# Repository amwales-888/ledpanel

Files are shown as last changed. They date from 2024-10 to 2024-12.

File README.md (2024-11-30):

# ledpanel
32x32 LED panel

Using 16 8x8 1.9mm LED modules to make a larger 32x32 8cm panel.
Adding shift registers and a small py32 microcontroller to multiplex the display.
The panel is broken out into two boards, the first a simple breakout and the
second is a plugin board that holds the mcu and shift registers. The panel
design does not overhang any edges so multiple panels can be connected together.

<table>
  <tr>
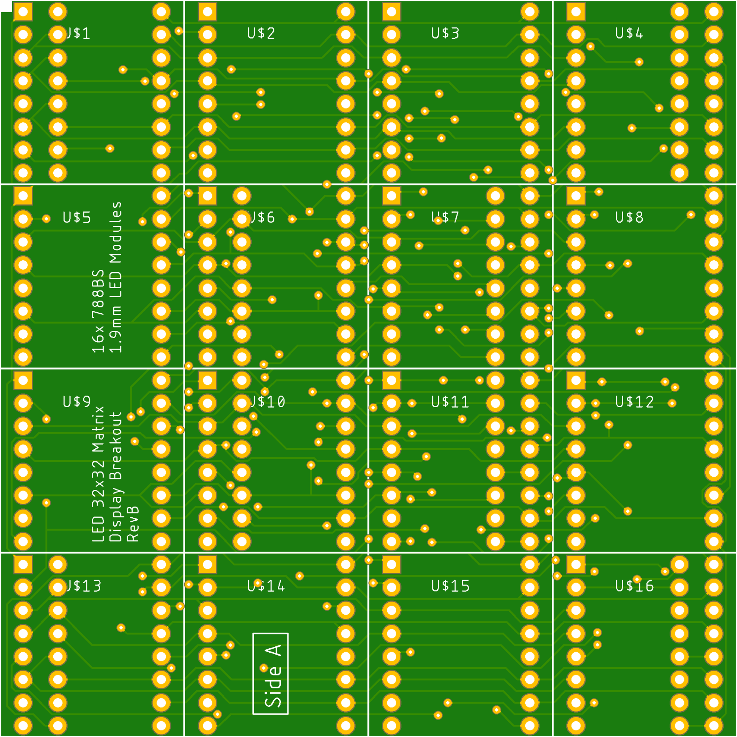
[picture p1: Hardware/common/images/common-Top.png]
    <td> </td>
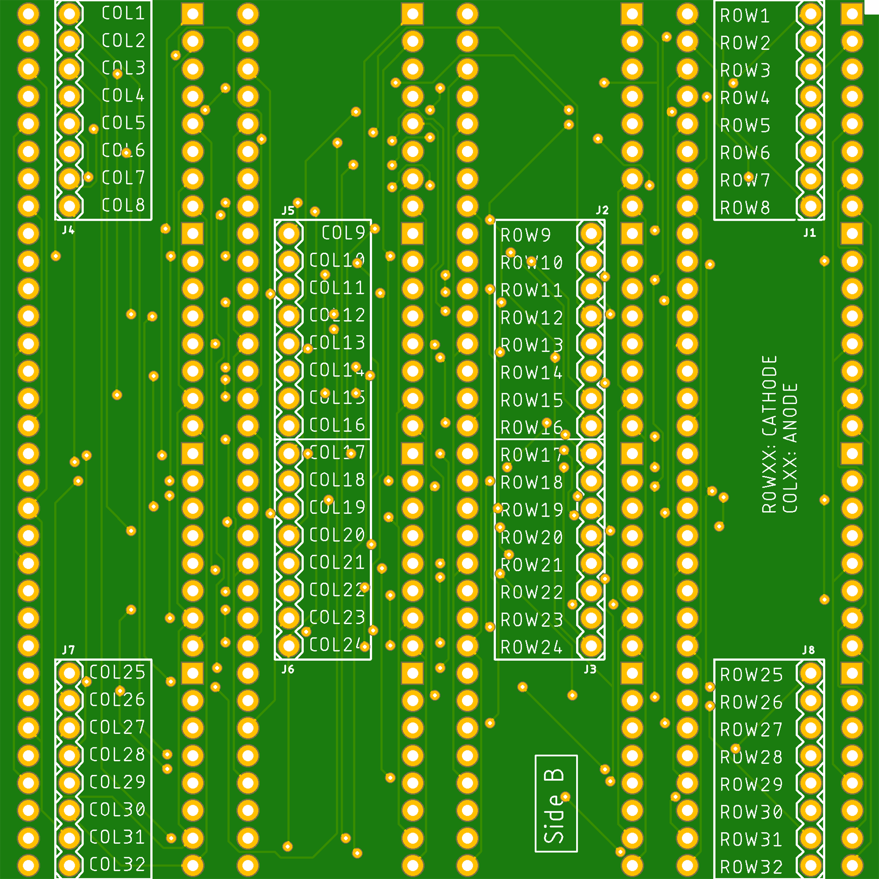
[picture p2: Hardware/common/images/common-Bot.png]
    <td> </td>
  </tr>
  <tr>
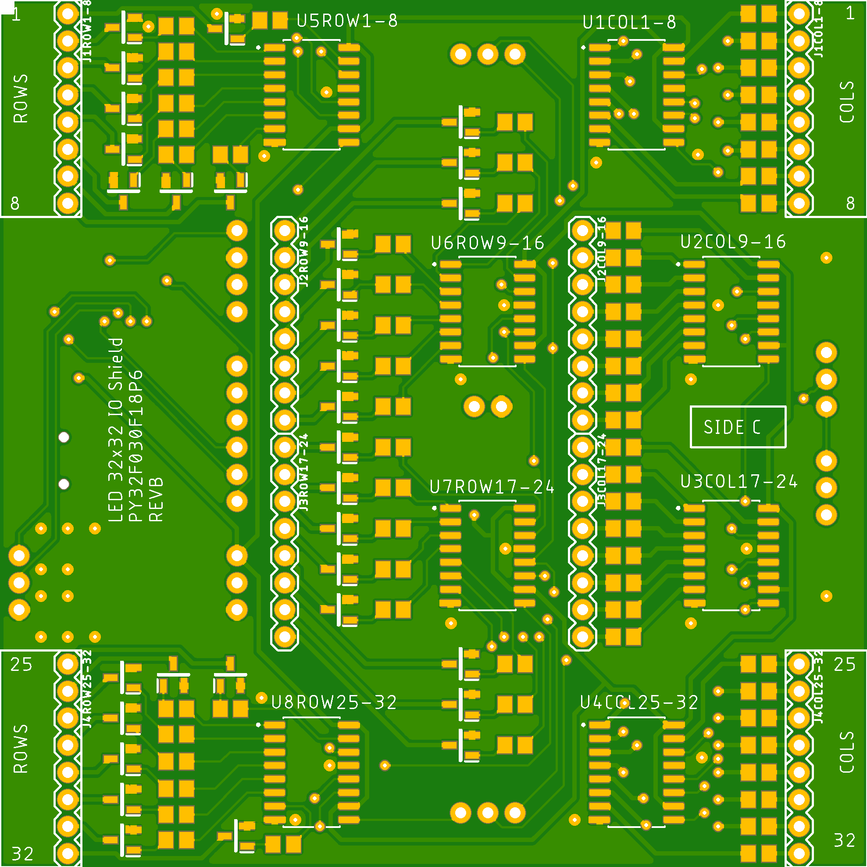
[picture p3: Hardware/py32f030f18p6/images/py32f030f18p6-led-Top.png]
    <td> </td>
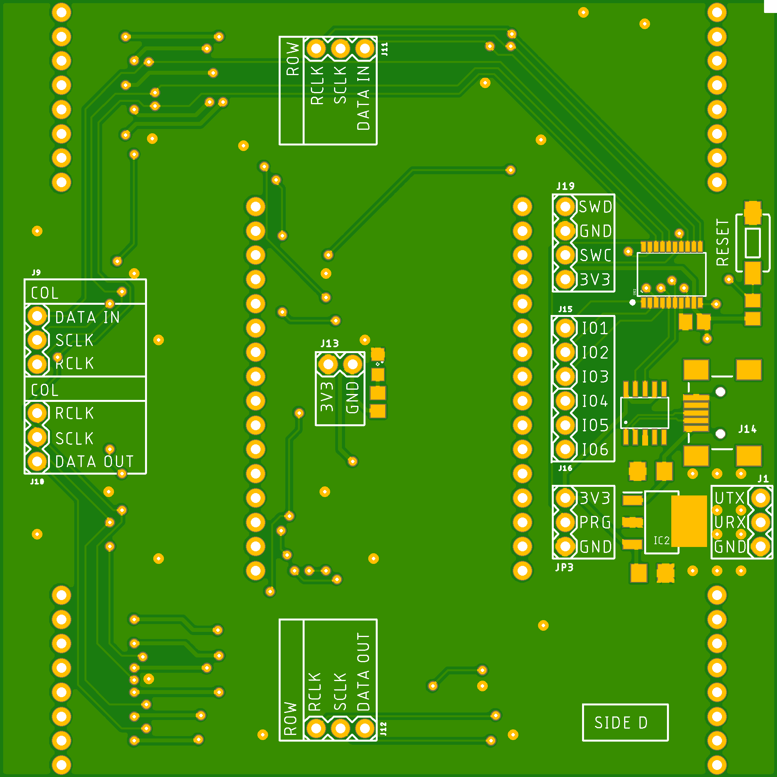
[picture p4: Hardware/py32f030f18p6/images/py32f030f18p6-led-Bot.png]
    <td> </td>
  </tr>
</table>

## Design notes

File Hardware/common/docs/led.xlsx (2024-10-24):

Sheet: Sheet1
 | 0 | 1 | 2 | 3 | 4
0 | 0 | 0 | 1 | 0 | 0 | 0 | 66 | 127 | 64 | 0
1 | 0 | 1 | 1 | 0 | 0
2 | 0 | 0 | 1 | 0 | 0
3 | 0 | 0 | 1 | 0 | 0
4 | 0 | 0 | 1 | 0 | 0
5 | 0 | 0 | 1 | 0 | 0
6 | 0 | 1 | 1 | 1 | 0
7 | 0 | 0 | 0 | 0 | 0
0 | 0 | 1 | 1 | 1 | 0 | 66 | 97 | 81 | 73 | 70
1 | 1 | 0 | 0 | 0 | 1
2 | 0 | 0 | 0 | 0 | 1
3 | 0 | 0 | 0 | 1 | 0
4 | 0 | 0 | 1 | 0 | 0
5 | 0 | 1 | 0 | 0 | 0
6 | 1 | 1 | 1 | 1 | 1
7 | 0 | 0 | 0 | 0 | 0
0 | 1 | 1 | 1 | 1 | 0 | 65 | 73 | 73 | 73 | 54
1 | 0 | 0 | 0 | 0 | 1
2 | 0 | 0 | 0 | 0 | 1
3 | 0 | 1 | 1 | 1 | 0
4 | 0 | 0 | 0 | 0 | 1
5 | 0 | 0 | 0 | 0 | 1
6 | 1 | 1 | 1 | 1 | 0
7 | 0 | 0 | 0 | 0 | 0
0 | 1 | 0 | 0 | 0 | 1 | 15 | 8 | 8 | 8 | 127
1 | 1 | 0 | 0 | 0 | 1
2 | 1 | 0 | 0 | 0 | 1
3 | 1 | 1 | 1 | 1 | 1
4 | 0 | 0 | 0 | 0 | 1
5 | 0 | 0 | 0 | 0 | 1
6 | 0 | 0 | 0 | 0 | 1
7 | 0 | 0 | 0 | 0 | 0
0 | 1 | 1 | 1 | 1 | 1 | 79 | 73 | 73 | 73 | 49
1 | 1 | 0 | 0 | 0 | 0
2 | 1 | 0 | 0 | 0 | 0
3 | 1 | 1 | 1 | 1 | 0
4 | 0 | 0 | 0 | 0 | 1
5 | 0 | 0 | 0 | 0 | 1
6 | 1 | 1 | 1 | 1 | 0
7 | 0 | 0 | 0 | 0 | 0
0 | 0 | 1 | 1 | 1 | 0 | 62 | 73 | 73 | 73 | 48
1 | 1 | 0 | 0 | 0 | 0
2 | 1 | 0 | 0 | 0 | 0
3 | 1 | 1 | 1 | 1 | 0
4 | 1 | 0 | 0 | 0 | 1
5 | 1 | 0 | 0 | 0 | 1
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

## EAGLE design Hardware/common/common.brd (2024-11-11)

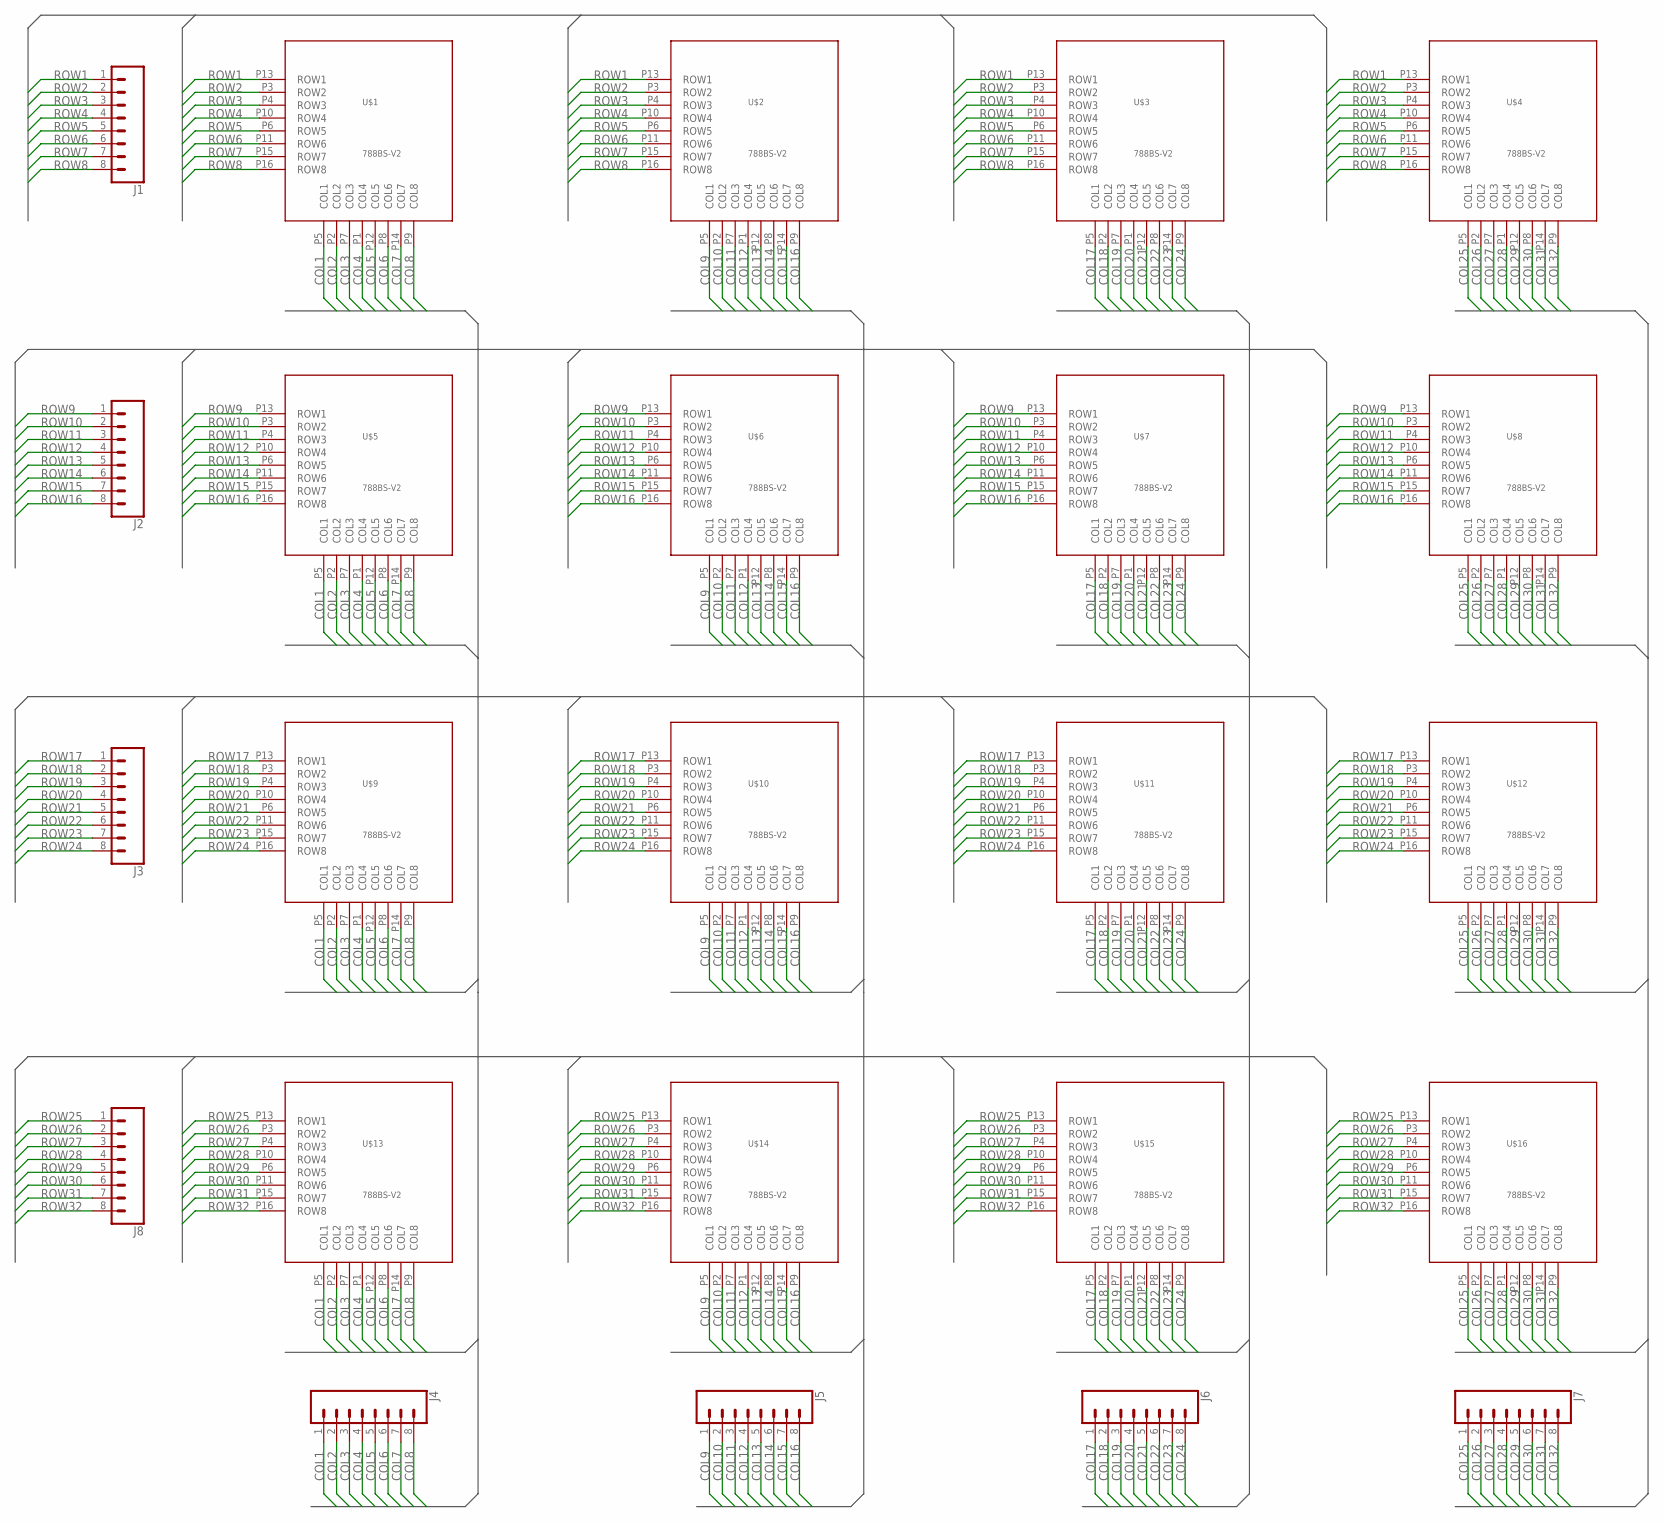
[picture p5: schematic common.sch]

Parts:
J1, J2, J3, J4, J5, J6, J7, J8: CONN_08"; 1X08
U$1, U$2, U$3, U$4, U$5, U$6, U$7, U$8, U$9, U$10, U$11, U$12, U$13, U$14, U$15, U$16: 788BS-V2; 788BS8X81.9MM-V2

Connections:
COL1: J4.1, U$1.P5 (COL1), U$5.P5 (COL1), U$9.P5 (COL1), U$13.P5 (COL1)
COL2: J4.2, U$1.P2 (COL2), U$5.P2 (COL2), U$9.P2 (COL2), U$13.P2 (COL2)
COL3: J4.3, U$1.P7 (COL3), U$5.P7 (COL3), U$9.P7 (COL3), U$13.P7 (COL3)
COL4: J4.4, U$1.P1 (COL4), U$5.P1 (COL4), U$9.P1 (COL4), U$13.P1 (COL4)
COL5: J4.5, U$1.P12 (COL5), U$5.P12 (COL5), U$9.P12 (COL5), U$13.P12 (COL5)
COL6: J4.6, U$1.P8 (COL6), U$5.P8 (COL6), U$9.P8 (COL6), U$13.P8 (COL6)
COL7: J4.7, U$1.P14 (COL7), U$5.P14 (COL7), U$9.P14 (COL7), U$13.P14 (COL7)
COL8: J4.8, U$1.P9 (COL8), U$5.P9 (COL8), U$9.P9 (COL8), U$13.P9 (COL8)
COL9: J5.1, U$2.P5 (COL1), U$6.P5 (COL1), U$10.P5 (COL1), U$14.P5 (COL1)
COL10: J5.2, U$2.P2 (COL2), U$6.P2 (COL2), U$10.P2 (COL2), U$14.P2 (COL2)
COL11: J5.3, U$2.P7 (COL3), U$6.P7 (COL3), U$10.P7 (COL3), U$14.P7 (COL3)
COL12: J5.4, U$2.P1 (COL4), U$6.P1 (COL4), U$10.P1 (COL4), U$14.P1 (COL4)
COL13: J5.5, U$2.P12 (COL5), U$6.P12 (COL5), U$10.P12 (COL5), U$14.P12 (COL5)
COL14: J5.6, U$2.P8 (COL6), U$6.P8 (COL6), U$10.P8 (COL6), U$14.P8 (COL6)
COL15: J5.7, U$2.P14 (COL7), U$6.P14 (COL7), U$10.P14 (COL7), U$14.P14 (COL7)
COL16: J5.8, U$2.P9 (COL8), U$6.P9 (COL8), U$10.P9 (COL8), U$14.P9 (COL8)
COL17: J6.1, U$3.P5 (COL1), U$7.P5 (COL1), U$11.P5 (COL1), U$15.P5 (COL1)
COL18: J6.2, U$3.P2 (COL2), U$7.P2 (COL2), U$11.P2 (COL2), U$15.P2 (COL2)
COL19: J6.3, U$3.P7 (COL3), U$7.P7 (COL3), U$11.P7 (COL3), U$15.P7 (COL3)
COL20: J6.4, U$3.P1 (COL4), U$7.P1 (COL4), U$11.P1 (COL4), U$15.P1 (COL4)
COL21: J6.5, U$3.P12 (COL5), U$7.P12 (COL5), U$11.P12 (COL5), U$15.P12 (COL5)
COL22: J6.6, U$3.P8 (COL6), U$7.P8 (COL6), U$11.P8 (COL6), U$15.P8 (COL6)
COL23: J6.7, U$3.P14 (COL7), U$7.P14 (COL7), U$11.P14 (COL7), U$15.P14 (COL7)
COL24: J6.8, U$3.P9 (COL8), U$7.P9 (COL8), U$11.P9 (COL8), U$15.P9 (COL8)
COL25: J7.1, U$4.P5 (COL1), U$8.P5 (COL1), U$12.P5 (COL1), U$16.P5 (COL1)
COL26: J7.2, U$4.P2 (COL2), U$8.P2 (COL2), U$12.P2 (COL2), U$16.P2 (COL2)
COL27: J7.3, U$4.P7 (COL3), U$8.P7 (COL3), U$12.P7 (COL3), U$16.P7 (COL3)
COL28: J7.4, U$4.P1 (COL4), U$8.P1 (COL4), U$12.P1 (COL4), U$16.P1 (COL4)
COL29: J7.5, U$4.P12 (COL5), U$8.P12 (COL5), U$12.P12 (COL5), U$16.P12 (COL5)
COL30: J7.6, U$4.P8 (COL6), U$8.P8 (COL6), U$12.P8 (COL6), U$16.P8 (COL6)
COL31: J7.7, U$4.P14 (COL7), U$8.P14 (COL7), U$12.P14 (COL7), U$16.P14 (COL7)
COL32: J7.8, U$4.P9 (COL8), U$8.P9 (COL8), U$12.P9 (COL8), U$16.P9 (COL8)
ROW1: J1.1, U$1.P13 (ROW1), U$2.P13 (ROW1), U$3.P13 (ROW1), U$4.P13 (ROW1)
ROW2: J1.2, U$1.P3 (ROW2), U$2.P3 (ROW2), U$3.P3 (ROW2), U$4.P3 (ROW2)
ROW3: J1.3, U$1.P4 (ROW3), U$2.P4 (ROW3), U$3.P4 (ROW3), U$4.P4 (ROW3)
ROW4: J1.4, U$1.P10 (ROW4), U$2.P10 (ROW4), U$3.P10 (ROW4), U$4.P10 (ROW4)
ROW5: J1.5, U$1.P6 (ROW5), U$2.P6 (ROW5), U$3.P6 (ROW5), U$4.P6 (ROW5)
ROW6: J1.6, U$1.P11 (ROW6), U$2.P11 (ROW6), U$3.P11 (ROW6), U$4.P11 (ROW6)
ROW7: J1.7, U$1.P15 (ROW7), U$2.P15 (ROW7), U$3.P15 (ROW7), U$4.P15 (ROW7)
ROW8: J1.8, U$1.P16 (ROW8), U$2.P16 (ROW8), U$3.P16 (ROW8), U$4.P16 (ROW8)
ROW9: J2.1, U$5.P13 (ROW1), U$6.P13 (ROW1), U$7.P13 (ROW1), U$8.P13 (ROW1)
ROW10: J2.2, U$5.P3 (ROW2), U$6.P3 (ROW2), U$7.P3 (ROW2), U$8.P3 (ROW2)
ROW11: J2.3, U$5.P4 (ROW3), U$6.P4 (ROW3), U$7.P4 (ROW3), U$8.P4 (ROW3)
ROW12: J2.4, U$5.P10 (ROW4), U$6.P10 (ROW4), U$7.P10 (ROW4), U$8.P10 (ROW4)
ROW13: J2.5, U$5.P6 (ROW5), U$6.P6 (ROW5), U$7.P6 (ROW5), U$8.P6 (ROW5)
ROW14: J2.6, U$5.P11 (ROW6), U$6.P11 (ROW6), U$7.P11 (ROW6), U$8.P11 (ROW6)
ROW15: J2.7, U$5.P15 (ROW7), U$6.P15 (ROW7), U$7.P15 (ROW7), U$8.P15 (ROW7)
ROW16: J2.8, U$5.P16 (ROW8), U$6.P16 (ROW8), U$7.P16 (ROW8), U$8.P16 (ROW8)
ROW17: J3.1, U$9.P13 (ROW1), U$10.P13 (ROW1), U$11.P13 (ROW1), U$12.P13 (ROW1)
ROW18: J3.2, U$9.P3 (ROW2), U$10.P3 (ROW2), U$11.P3 (ROW2), U$12.P3 (ROW2)
ROW19: J3.3, U$9.P4 (ROW3), U$10.P4 (ROW3), U$11.P4 (ROW3), U$12.P4 (ROW3)
ROW20: J3.4, U$9.P10 (ROW4), U$10.P10 (ROW4), U$11.P10 (ROW4), U$12.P10 (ROW4)
ROW21: J3.5, U$9.P6 (ROW5), U$10.P6 (ROW5), U$11.P6 (ROW5), U$12.P6 (ROW5)
ROW22: J3.6, U$9.P11 (ROW6), U$10.P11 (ROW6), U$11.P11 (ROW6), U$12.P11 (ROW6)
ROW23: J3.7, U$9.P15 (ROW7), U$10.P15 (ROW7), U$11.P15 (ROW7), U$12.P15 (ROW7)
ROW24: J3.8, U$9.P16 (ROW8), U$10.P16 (ROW8), U$11.P16 (ROW8), U$12.P16 (ROW8)
ROW25: J8.1, U$13.P13 (ROW1), U$14.P13 (ROW1), U$15.P13 (ROW1), U$16.P13 (ROW1)
ROW26: J8.2, U$13.P3 (ROW2), U$14.P3 (ROW2), U$15.P3 (ROW2), U$16.P3 (ROW2)
ROW27: J8.3, U$13.P4 (ROW3), U$14.P4 (ROW3), U$15.P4 (ROW3), U$16.P4 (ROW3)
ROW28: J8.4, U$13.P10 (ROW4), U$14.P10 (ROW4), U$15.P10 (ROW4), U$16.P10 (ROW4)
ROW29: J8.5, U$13.P6 (ROW5), U$14.P6 (ROW5), U$15.P6 (ROW5), U$16.P6 (ROW5)
ROW30: J8.6, U$13.P11 (ROW6), U$14.P11 (ROW6), U$15.P11 (ROW6), U$16.P11 (ROW6)
ROW31: J8.7, U$13.P15 (ROW7), U$14.P15 (ROW7), U$15.P15 (ROW7), U$16.P15 (ROW7)
ROW32: J8.8, U$13.P16 (ROW8), U$14.P16 (ROW8), U$15.P16 (ROW8), U$16.P16 (ROW8)

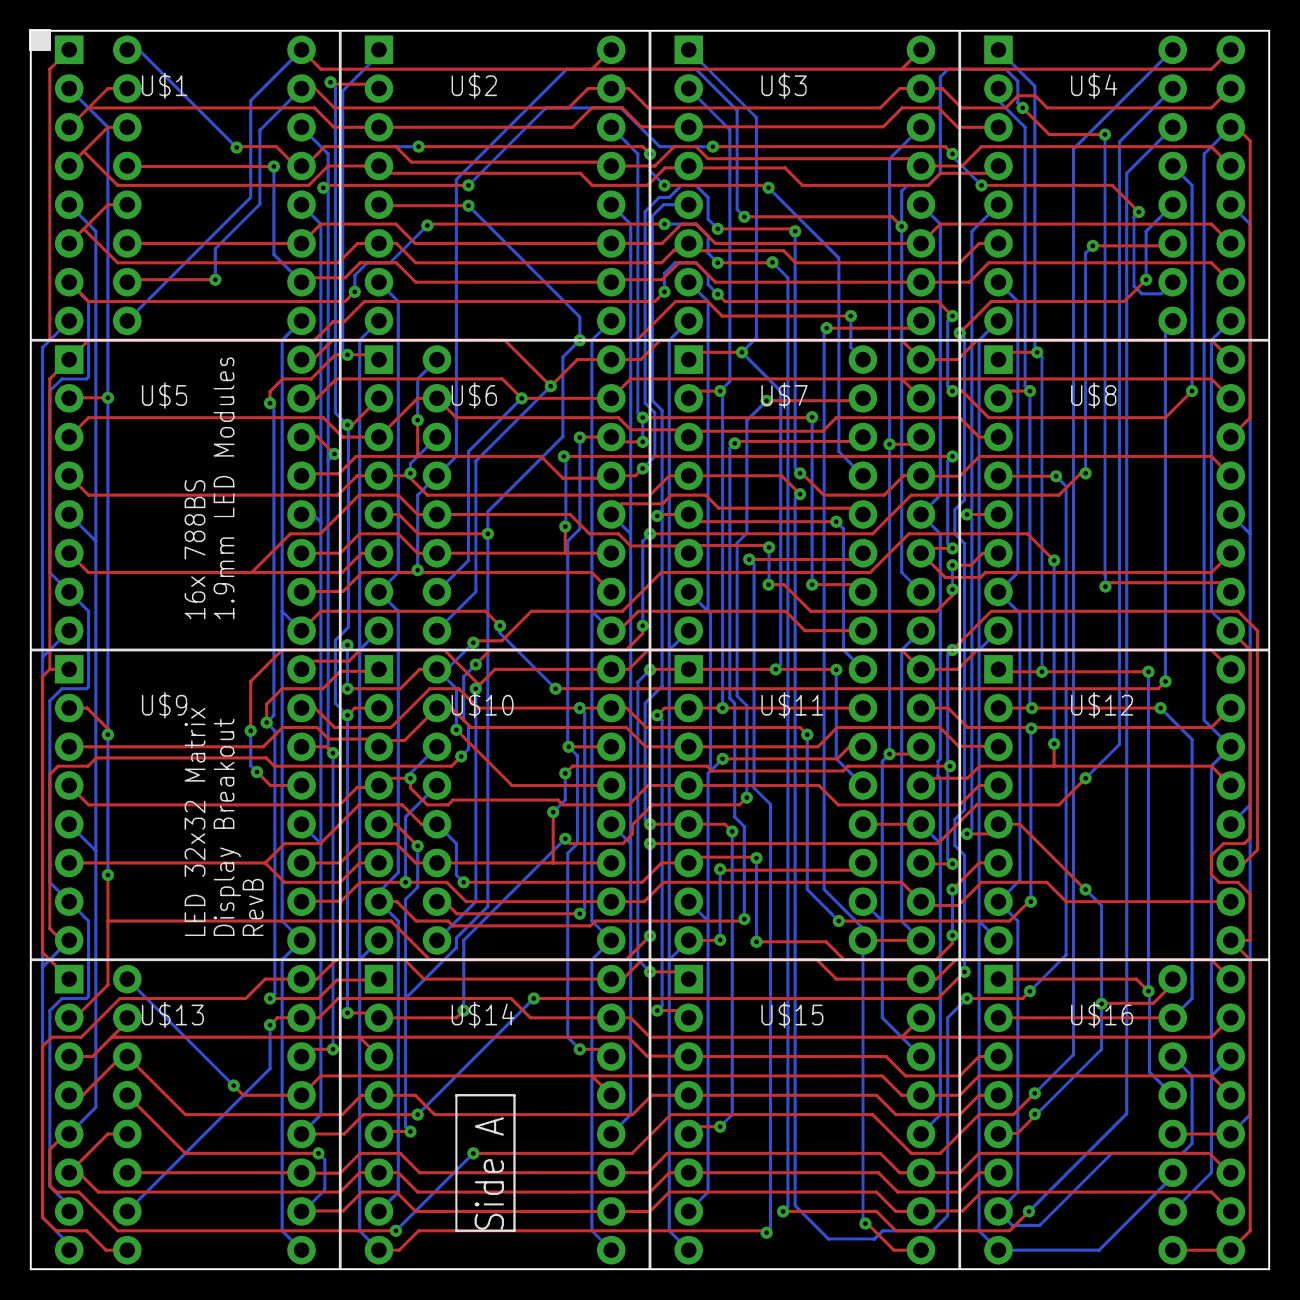
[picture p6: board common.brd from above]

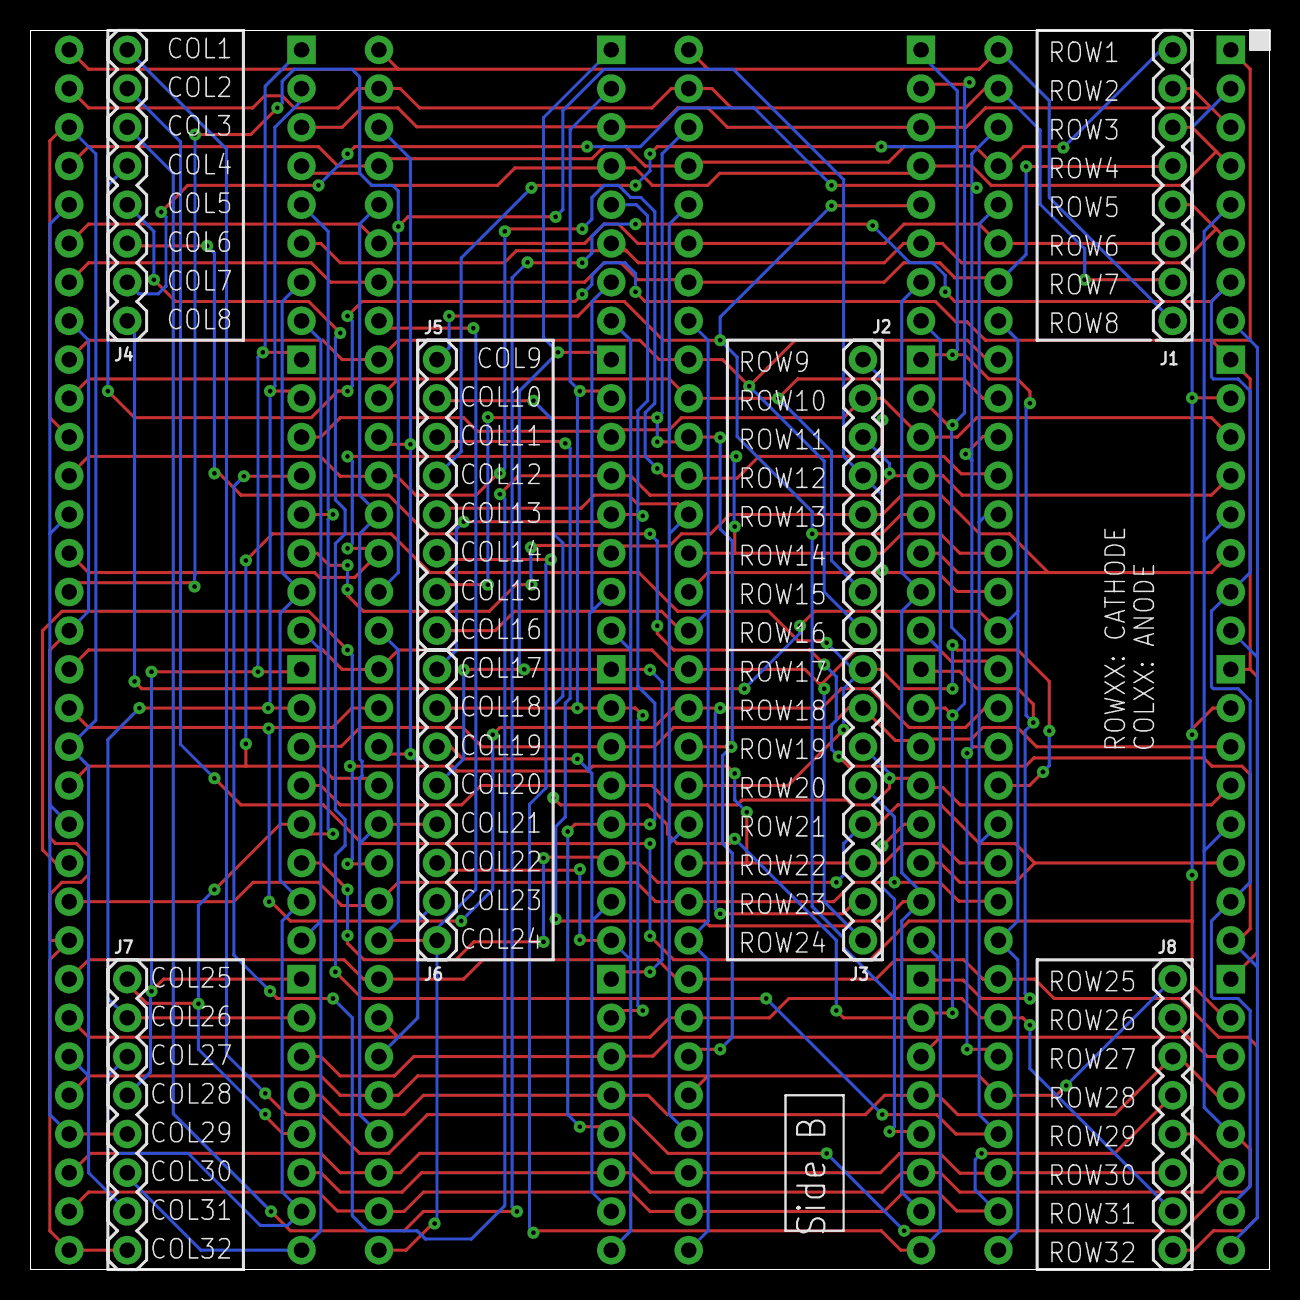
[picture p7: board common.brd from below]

Board: 2 copper layers, 81.3 x 81.3 mm, 24 parts (8 on the bottom side), 64 nets.

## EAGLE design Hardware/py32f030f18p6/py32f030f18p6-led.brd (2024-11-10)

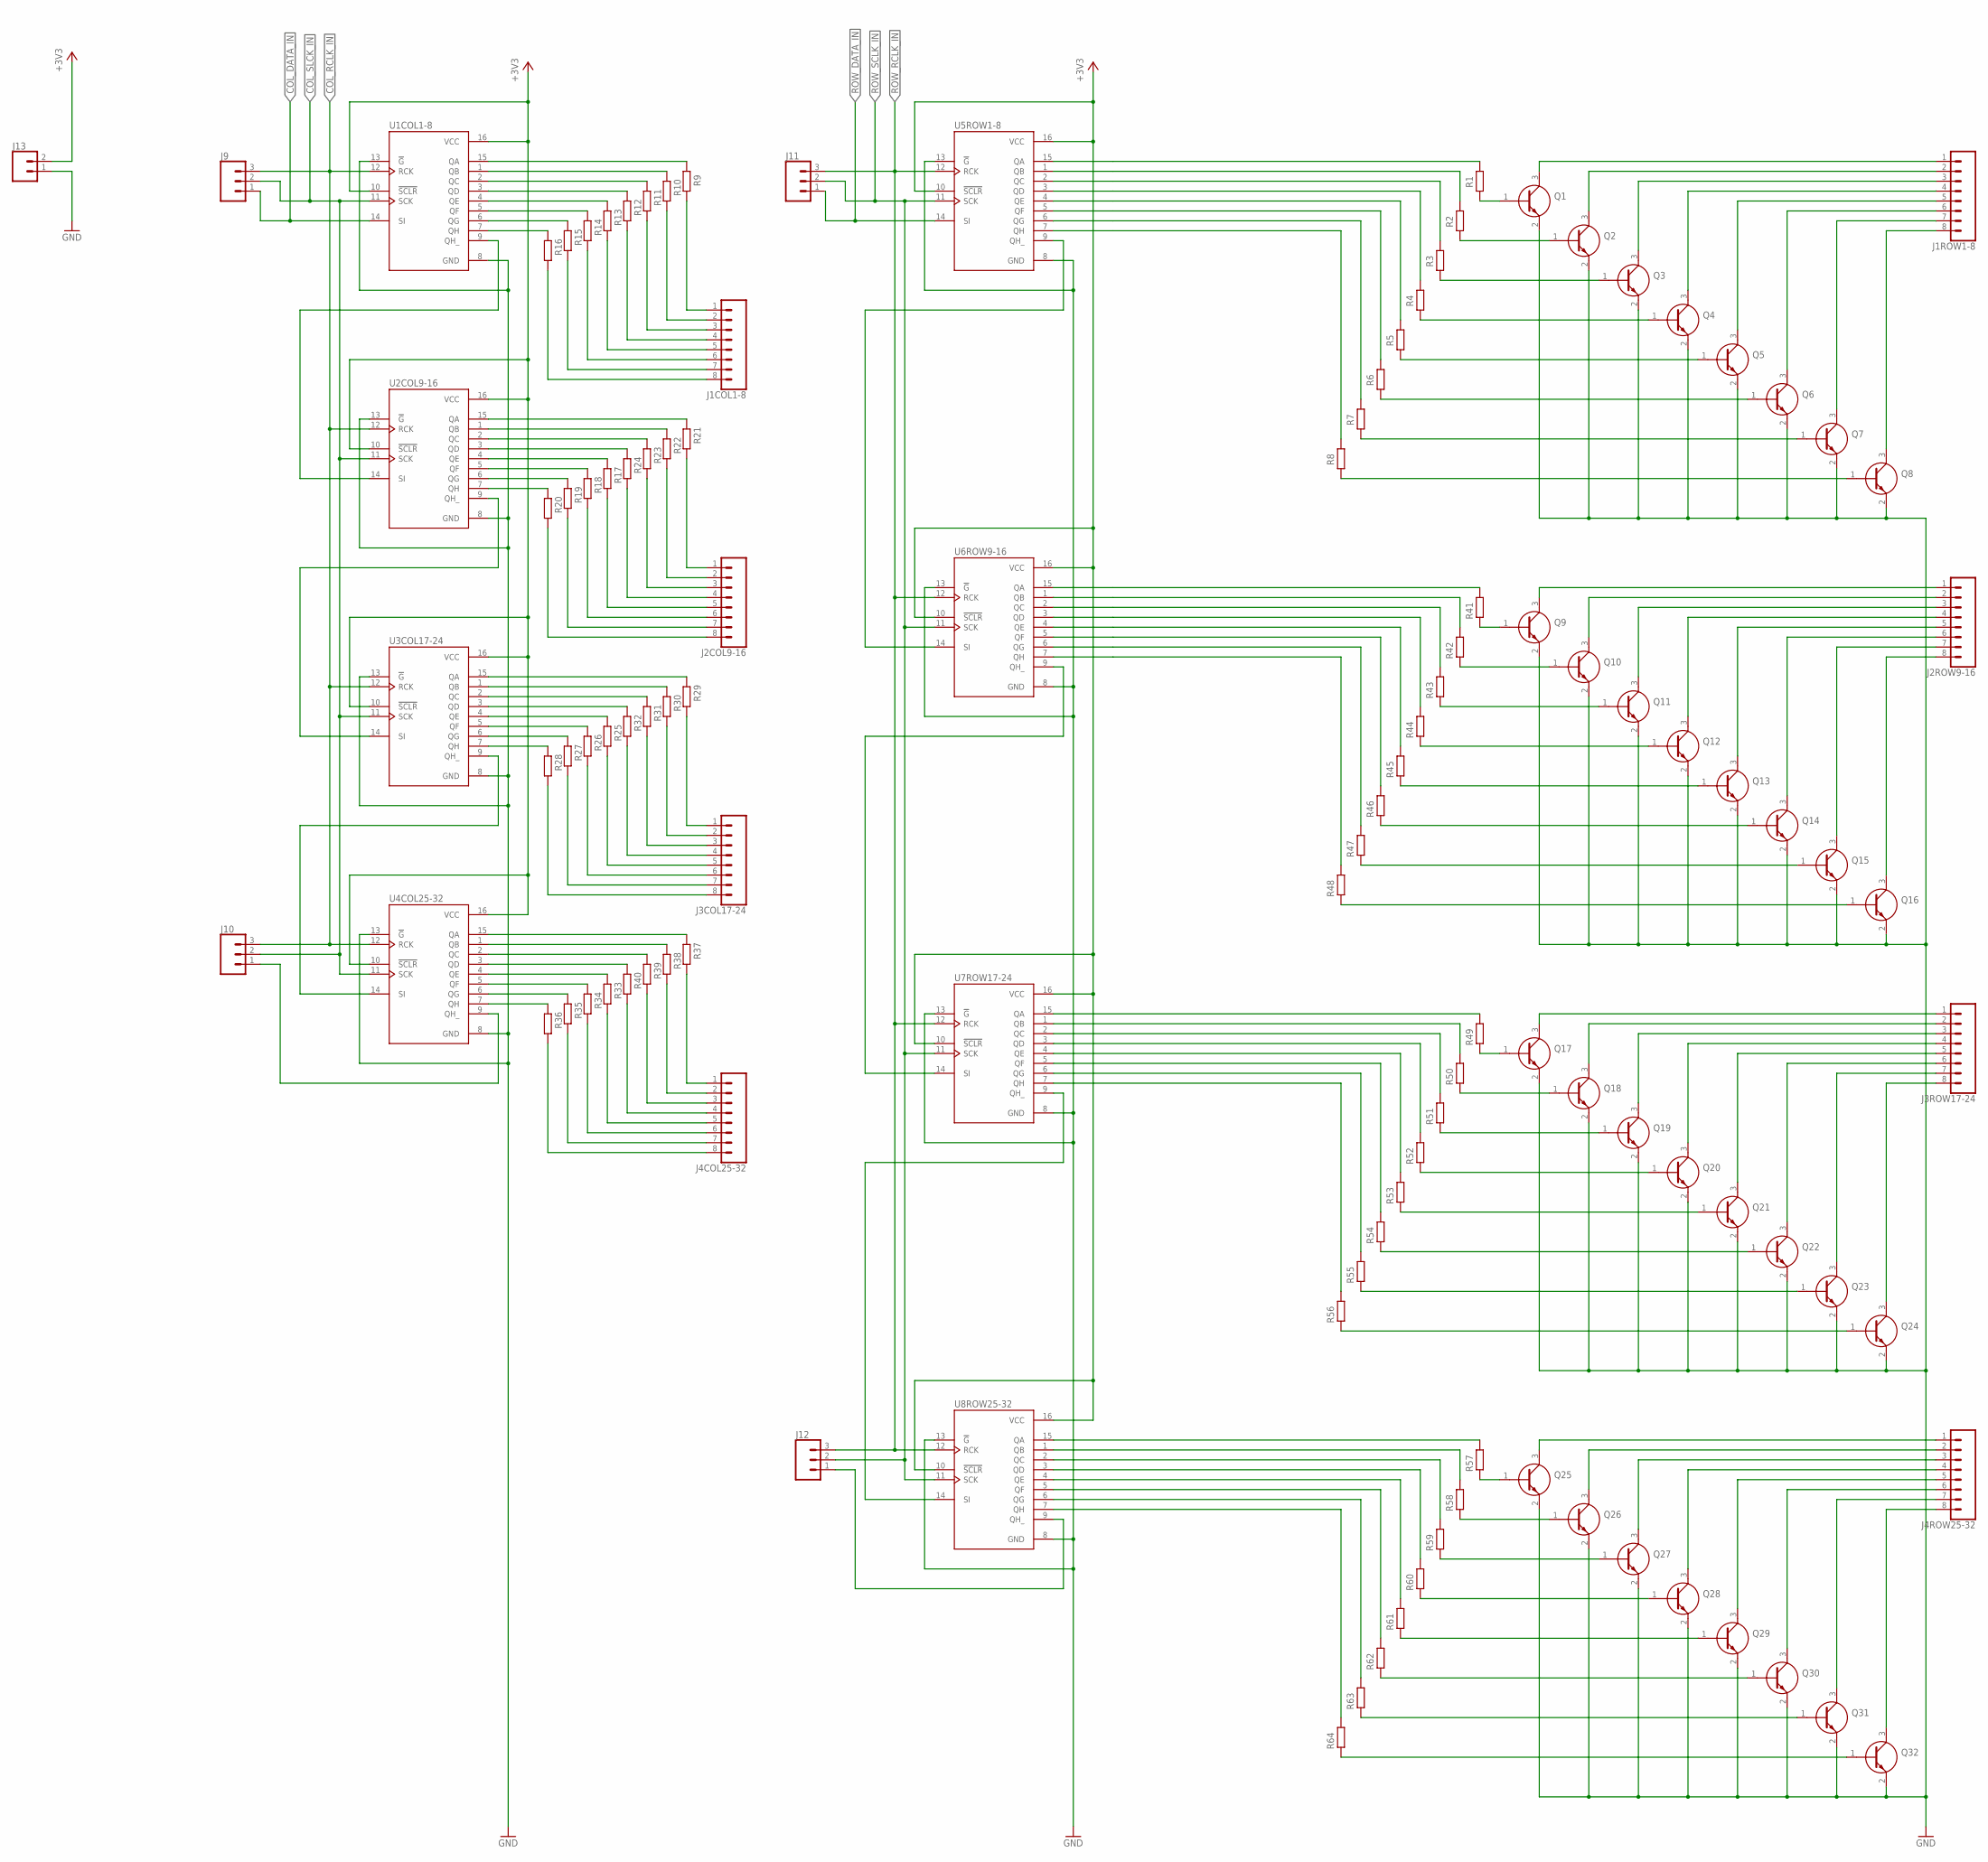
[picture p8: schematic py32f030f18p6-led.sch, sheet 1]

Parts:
J1COL1-8, J1ROW1-8, J2COL9-16, J2ROW9-16, J3COL17-24, J3ROW17-24, J4COL25-32, J4ROW25-32: CONN_08"; 1X08
J9, J10, J11, J12: 455-1750-1-ND; 1X03
J13: CONN_02; 1X02
Q1, Q2, Q3, Q4, Q5, Q6, Q7, Q8, Q9, Q10, Q11, Q12, Q13, Q14, Q15, Q16, Q17, Q18, Q19, Q20, Q21, Q22, Q23, Q24, Q25, Q26, Q27, Q28, Q29, Q30, Q31, Q32: MMBT3904LT3G; SOT96P237X111-3N
R1, R2, R3, R4, R5, R6, R7, R8, R9, R10, R11, R12, R13, R14, R15, R16, R17, R18, R19, R20, R21, R22, R23, R24, R25, R26, R27, R28, R29, R30, R31, R32, R33, R34, R35, R36, R37, R38, R39, R40, R41, R42, R43, R44, R45, R46, R47, R48, R49, R50, R51, R52, R53, R54, R55, R56, R57, R58, R59, R60, R61, R62, R63, R64: 10K; R0805
U1COL1-8, U2COL9-16, U3COL17-24, U4COL25-32, U5ROW1-8, U6ROW9-16, U7ROW17-24, U8ROW25-32: TC74HC595AF(EL,F); SOIC127P780X190-16N

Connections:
+3V3: J13.2, U1COL1-8.10 (!SCLR), U1COL1-8.16 (VCC), U2COL9-16.10 (!SCLR), U2COL9-16.16 (VCC), U3COL17-24.10 (!SCLR), U3COL17-24.16 (VCC), U4COL25-32.10 (!SCLR), U4COL25-32.16 (VCC), U5ROW1-8.10 (!SCLR), U5ROW1-8.16 (VCC), U6ROW9-16.10 (!SCLR), U6ROW9-16.16 (VCC), U7ROW17-24.10 (!SCLR), U7ROW17-24.16 (VCC), U8ROW25-32.10 (!SCLR), U8ROW25-32.16 (VCC); also elsewhere on the board
COL_DATA_IN: J9.1, U1COL1-8.14 (SI); also elsewhere on the board
COL_RCLK_IN: J9.3, J10.3, U1COL1-8.12 (RCK), U2COL9-16.12 (RCK), U3COL17-24.12 (RCK), U4COL25-32.12 (RCK); also elsewhere on the board
COL_SLCK_IN: J9.2, J10.2, U1COL1-8.11 (SCK), U2COL9-16.11 (SCK), U3COL17-24.11 (SCK), U4COL25-32.11 (SCK); also elsewhere on the board
GND: J13.1, Q1.2 (E), Q2.2 (E), Q3.2 (E), Q4.2 (E), Q5.2 (E), Q6.2 (E), Q7.2 (E), Q8.2 (E), Q9.2 (E), Q10.2 (E), Q11.2 (E), Q12.2 (E), Q13.2 (E), Q14.2 (E), Q15.2 (E), Q16.2 (E), Q17.2 (E), Q18.2 (E), Q19.2 (E), Q20.2 (E), Q21.2 (E), Q22.2 (E), Q23.2 (E), Q24.2 (E), Q25.2 (E), Q26.2 (E), Q27.2 (E), Q28.2 (E), Q29.2 (E), Q30.2 (E), Q31.2 (E), Q32.2 (E), U1COL1-8.8 (GND), U1COL1-8.13 (!G), U2COL9-16.8 (GND), U2COL9-16.13 (!G), U3COL17-24.8 (GND), U3COL17-24.13 (!G), U4COL25-32.8 (GND), U4COL25-32.13 (!G), U5ROW1-8.8 (GND), U5ROW1-8.13 (!G), U6ROW9-16.8 (GND), U6ROW9-16.13 (!G), U7ROW17-24.8 (GND), U7ROW17-24.13 (!G), U8ROW25-32.8 (GND), U8ROW25-32.13 (!G); also elsewhere on the board
unnamed: J1ROW1-8.1, Q1.3 (C)
unnamed: J1ROW1-8.2, Q2.3 (C)
unnamed: J1ROW1-8.3, Q3.3 (C)
unnamed: J1ROW1-8.4, Q4.3 (C)
unnamed: J1ROW1-8.5, Q5.3 (C)
unnamed: J1ROW1-8.6, Q6.3 (C)
unnamed: J1ROW1-8.7, Q7.3 (C)
unnamed: J1ROW1-8.8, Q8.3 (C)
unnamed: R13.2, U1COL1-8.4 (QE)
unnamed: Q1.1 (B), R1.2
unnamed: Q2.1 (B), R2.2
unnamed: Q3.1 (B), R3.2
unnamed: Q4.1 (B), R4.2
unnamed: Q5.1 (B), R5.2
unnamed: Q6.1 (B), R6.2
unnamed: Q7.1 (B), R7.2
unnamed: Q8.1 (B), R8.2
unnamed: R12.2, U1COL1-8.3 (QD)
unnamed: R11.2, U1COL1-8.2 (QC)
unnamed: R14.2, U1COL1-8.5 (QF)
unnamed: R16.2, U1COL1-8.7 (QH)
unnamed: R15.2, U1COL1-8.6 (QG)
unnamed: R10.2, U1COL1-8.1 (QB)
unnamed: R9.2, U1COL1-8.15 (QA)
unnamed: J1COL1-8.3, R11.1
unnamed: J1COL1-8.4, R12.1
unnamed: J1COL1-8.5, R13.1
unnamed: J1COL1-8.6, R14.1
unnamed: J1COL1-8.7, R15.1
unnamed: J1COL1-8.8, R16.1
unnamed: Q9.1 (B), R41.2
unnamed: R20.2, U2COL9-16.7 (QH)
unnamed: R19.2, U2COL9-16.6 (QG)
unnamed: J1COL1-8.2, R10.1
unnamed: R18.2, U2COL9-16.5 (QF)
unnamed: R17.2, U2COL9-16.4 (QE)
unnamed: J1COL1-8.1, R9.1
unnamed: R24.2, U2COL9-16.3 (QD)
unnamed: R23.2, U2COL9-16.2 (QC)
unnamed: R22.2, U2COL9-16.1 (QB)
unnamed: R21.2, U2COL9-16.15 (QA)
unnamed: J2COL9-16.2, R22.1
unnamed: J2COL9-16.1, R21.1
unnamed: J2COL9-16.3, R23.1
unnamed: J2COL9-16.4, R24.1
unnamed: Q10.1 (B), R42.2
unnamed: J2COL9-16.5, R17.1
unnamed: J2COL9-16.6, R18.1
unnamed: J2COL9-16.7, R19.1
unnamed: J2COL9-16.8, R20.1
unnamed: U2COL9-16.9 (QH_), U3COL17-24.14 (SI)
unnamed: U1COL1-8.9 (QH_), U2COL9-16.14 (SI)
unnamed: Q11.1 (B), R43.2
unnamed: Q12.1 (B), R44.2
unnamed: Q13.1 (B), R45.2
unnamed: R28.2, U3COL17-24.7 (QH)
unnamed: R27.2, U3COL17-24.6 (QG)
unnamed: R26.2, U3COL17-24.5 (QF)
unnamed: R25.2, U3COL17-24.4 (QE)
unnamed: R32.2, U3COL17-24.3 (QD)
unnamed: R31.2, U3COL17-24.2 (QC)
unnamed: R30.2, U3COL17-24.1 (QB)
unnamed: R29.2, U3COL17-24.15 (QA)
unnamed: J3COL17-24.2, R30.1
unnamed: J3COL17-24.1, R29.1
unnamed: J3COL17-24.3, R31.1
unnamed: J3COL17-24.4, R32.1
unnamed: J3COL17-24.5, R25.1
unnamed: J3COL17-24.6, R26.1
unnamed: J3COL17-24.7, R27.1
unnamed: J3COL17-24.8, R28.1
unnamed: U3COL17-24.9 (QH_), U4COL25-32.14 (SI)
unnamed: Q14.1 (B), R46.2
unnamed: Q15.1 (B), R47.2
unnamed: Q16.1 (B), R48.2
unnamed: R36.2, U4COL25-32.7 (QH)
unnamed: R35.2, U4COL25-32.6 (QG)
unnamed: R34.2, U4COL25-32.5 (QF)
unnamed: R33.2, U4COL25-32.4 (QE)
unnamed: R40.2, U4COL25-32.3 (QD)
unnamed: R39.2, U4COL25-32.2 (QC)
unnamed: R38.2, U4COL25-32.1 (QB)
unnamed: R37.2, U4COL25-32.15 (QA)
unnamed: J4COL25-32.2, R38.1
unnamed: J4COL25-32.1, R37.1
unnamed: J4COL25-32.3, R39.1
unnamed: J4COL25-32.4, R40.1
unnamed: J4COL25-32.5, R33.1
unnamed: J4COL25-32.6, R34.1
unnamed: J4COL25-32.7, R35.1
unnamed: J4COL25-32.8, R36.1
unnamed: J10.1, U4COL25-32.9 (QH_)
unnamed: J2ROW9-16.1, Q9.3 (C)
unnamed: J2ROW9-16.2, Q10.3 (C)
unnamed: J2ROW9-16.3, Q11.3 (C)
unnamed: J2ROW9-16.4, Q12.3 (C)
unnamed: J2ROW9-16.5, Q13.3 (C)
unnamed: J2ROW9-16.6, Q14.3 (C)
unnamed: J2ROW9-16.7, Q15.3 (C)
unnamed: J2ROW9-16.8, Q16.3 (C)
unnamed: Q17.1 (B), R49.2
unnamed: Q18.1 (B), R50.2
unnamed: Q19.1 (B), R51.2
unnamed: Q20.1 (B), R52.2
unnamed: Q21.1 (B), R53.2
unnamed: Q22.1 (B), R54.2
unnamed: Q23.1 (B), R55.2
unnamed: Q24.1 (B), R56.2
unnamed: J3ROW17-24.1, Q17.3 (C)
unnamed: J3ROW17-24.2, Q18.3 (C)
unnamed: J3ROW17-24.3, Q19.3 (C)
unnamed: J3ROW17-24.4, Q20.3 (C)
unnamed: J3ROW17-24.5, Q21.3 (C)
unnamed: J3ROW17-24.6, Q22.3 (C)
unnamed: J3ROW17-24.7, Q23.3 (C)
unnamed: J3ROW17-24.8, Q24.3 (C)
unnamed: Q25.1 (B), R57.2
unnamed: Q26.1 (B), R58.2
unnamed: Q27.1 (B), R59.2
unnamed: Q28.1 (B), R60.2
unnamed: Q29.1 (B), R61.2
unnamed: Q30.1 (B), R62.2
unnamed: Q31.1 (B), R63.2
unnamed: Q32.1 (B), R64.2
unnamed: J4ROW25-32.1, Q25.3 (C)
unnamed: J4ROW25-32.2, Q26.3 (C)
unnamed: J4ROW25-32.3, Q27.3 (C)
unnamed: J4ROW25-32.4, Q28.3 (C)
unnamed: J4ROW25-32.5, Q29.3 (C)
unnamed: J4ROW25-32.6, Q30.3 (C)
unnamed: J4ROW25-32.7, Q31.3 (C)
unnamed: J4ROW25-32.8, Q32.3 (C)
unnamed: R8.1, U5ROW1-8.7 (QH)
unnamed: R7.1, U5ROW1-8.6 (QG)
unnamed: R6.1, U5ROW1-8.5 (QF)
unnamed: R5.1, U5ROW1-8.4 (QE)
unnamed: R4.1, U5ROW1-8.3 (QD)
unnamed: R3.1, U5ROW1-8.2 (QC)
unnamed: R2.1, U5ROW1-8.1 (QB)
unnamed: R1.1, U5ROW1-8.15 (QA)
unnamed: R48.1, U6ROW9-16.7 (QH)
unnamed: R47.1, U6ROW9-16.6 (QG)
unnamed: R46.1, U6ROW9-16.5 (QF)
unnamed: R45.1, U6ROW9-16.4 (QE)
unnamed: R44.1, U6ROW9-16.3 (QD)
unnamed: R43.1, U6ROW9-16.2 (QC)
unnamed: R42.1, U6ROW9-16.1 (QB)
unnamed: R41.1, U6ROW9-16.15 (QA)
unnamed: U6ROW9-16.9 (QH_), U7ROW17-24.14 (SI)
unnamed: U5ROW1-8.9 (QH_), U6ROW9-16.14 (SI)
unnamed: R56.1, U7ROW17-24.7 (QH)
unnamed: R55.1, U7ROW17-24.6 (QG)
unnamed: R54.1, U7ROW17-24.5 (QF)
unnamed: R53.1, U7ROW17-24.4 (QE)
unnamed: R52.1, U7ROW17-24.3 (QD)
unnamed: R51.1, U7ROW17-24.2 (QC)
unnamed: R50.1, U7ROW17-24.1 (QB)
unnamed: R49.1, U7ROW17-24.15 (QA)
unnamed: U7ROW17-24.9 (QH_), U8ROW25-32.14 (SI)
unnamed: R64.1, U8ROW25-32.7 (QH)
unnamed: R63.1, U8ROW25-32.6 (QG)
unnamed: R62.1, U8ROW25-32.5 (QF)
unnamed: R61.1, U8ROW25-32.4 (QE)
unnamed: R60.1, U8ROW25-32.3 (QD)
unnamed: R59.1, U8ROW25-32.2 (QC)
unnamed: R58.1, U8ROW25-32.1 (QB)
unnamed: R57.1, U8ROW25-32.15 (QA)
unnamed: J12.1, U8ROW25-32.9 (QH_)
ROW_DATA_IN: J11.1, U5ROW1-8.14 (SI); also elsewhere on the board
ROW_RCLK_IN: J11.3, J12.3, U5ROW1-8.12 (RCK), U6ROW9-16.12 (RCK), U7ROW17-24.12 (RCK), U8ROW25-32.12 (RCK); also elsewhere on the board
ROW_SCLK_IN: J11.2, J12.2, U5ROW1-8.11 (SCK), U6ROW9-16.11 (SCK), U7ROW17-24.11 (SCK), U8ROW25-32.11 (SCK); also elsewhere on the board

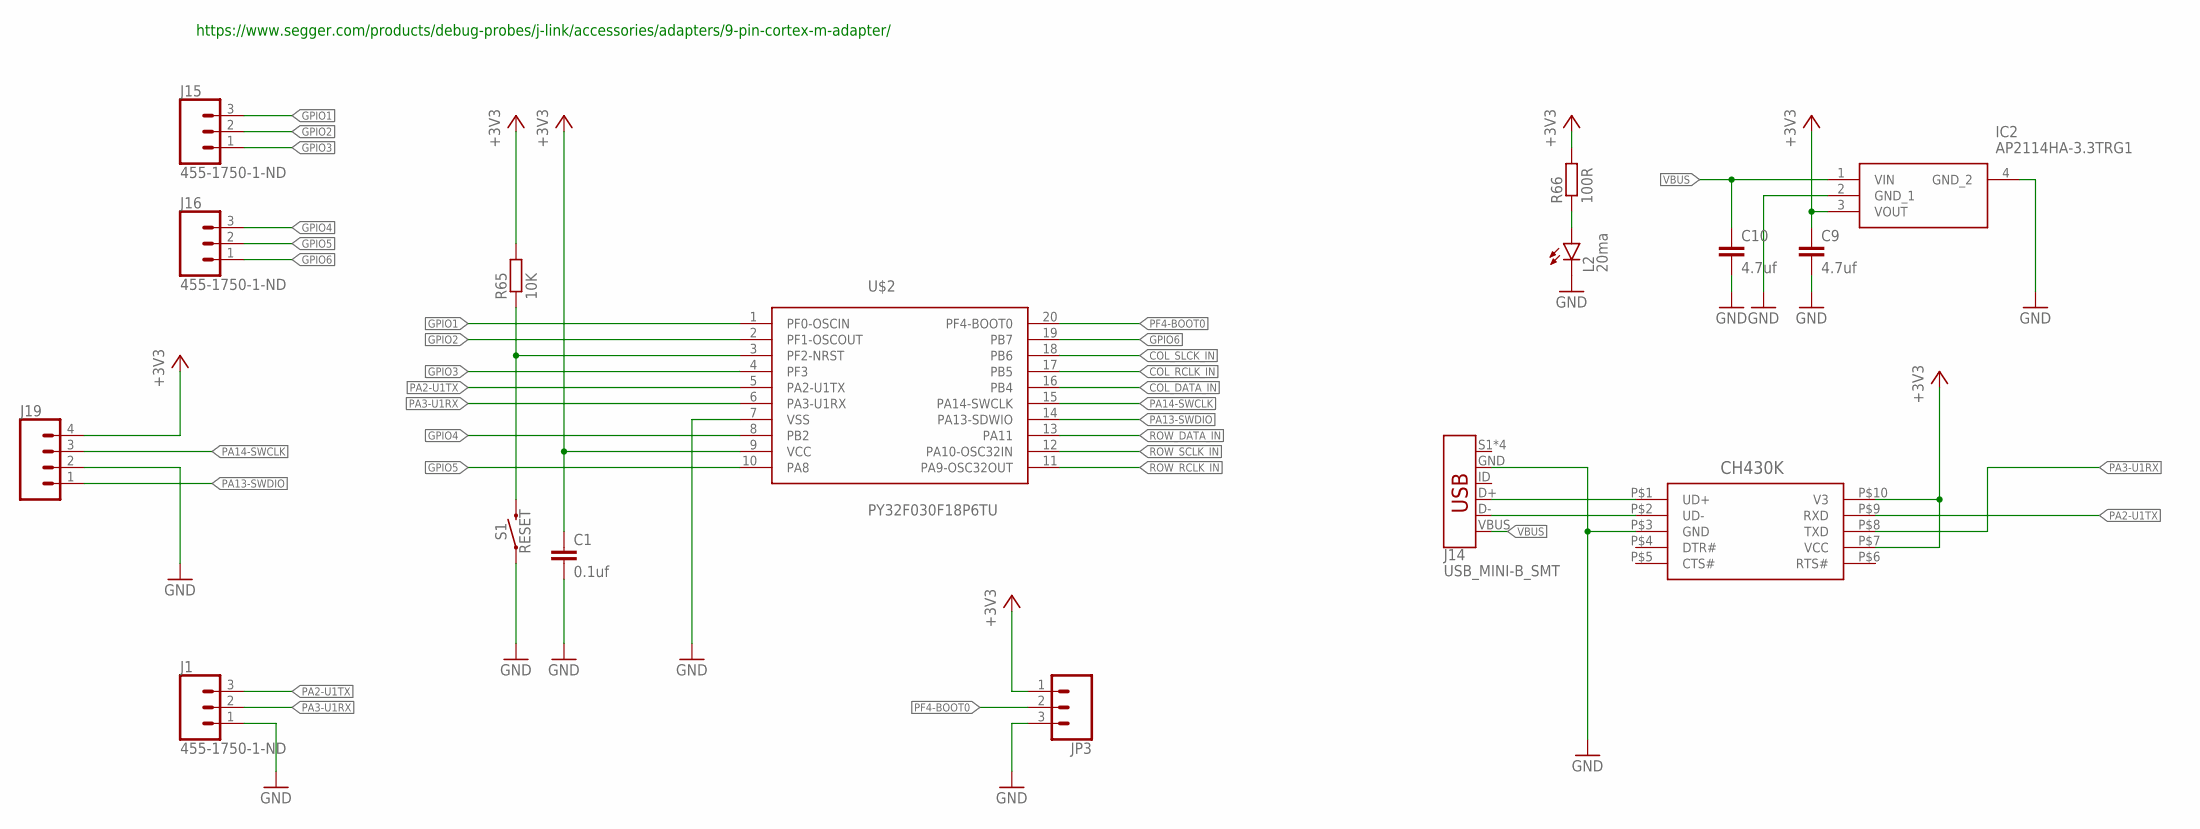
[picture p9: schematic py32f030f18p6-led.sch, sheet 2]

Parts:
C1: 0.1uf; C0805
C9, C10: 4.7uf; C1206
IC2: AP2114HA-3.3TRG1; SOT230P700X180-4N
J1, J15, J16: 455-1750-1-ND; 1X03
J14: USB_MINI-B_SMT; USB-MINIB
J19: CONN_04PTH; 1X04
JP3: 455-1750-1-ND; 1X03
L2: 20ma; SML0805
R65: 10K; R0805
R66: 100R; R0805
S1: RESET; TACTILE_SWITCH_SMD_6.0X3.5MM
U$1: CH430K; ESSOP-10
U$2: PY32F030F18P6TU; TSSOP20

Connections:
+3V3: C1.1, C9.1, IC2.3 (VOUT), J19.4, JP3.1, R65.2, R66.2, U$1.P$7 (VCC), U$1.P$10 (V3), U$2.9 (VCC); also elsewhere on the board
COL_DATA_IN: U$2.16 (PB4); also elsewhere on the board
COL_RCLK_IN: U$2.17 (PB5); also elsewhere on the board
COL_SLCK_IN: U$2.18 (PB6); also elsewhere on the board
GND: C1.2, C9.2, C10.2, IC2.2 (GND_1), IC2.4 (GND_2), J1.1, J14.GND, J19.2, JP3.3, L2.C, S1.1, U$1.P$3 (GND), U$2.7 (VSS); also elsewhere on the board
GPIO1: J15.3, U$2.1 (PF0-OSCIN)
GPIO2: J15.2, U$2.2 (PF1-OSCOUT)
GPIO3: J15.1, U$2.4 (PF3)
GPIO4: J16.3, U$2.8 (PB2)
GPIO5: J16.2, U$2.10 (PA8)
GPIO6: J16.1, U$2.19 (PB7)
unnamed: L2.A, R66.1
PA2-U1TX: J1.3, U$1.P$9 (RXD), U$2.5 (PA2-U1TX)
PA3-U1RX: J1.2, U$1.P$8 (TXD), U$2.6 (PA3-U1RX)
PA13-SWDIO: J19.1, U$2.14 (PA13-SDWIO)
PA14-SWCLK: J19.3, U$2.15 (PA14-SWCLK)
PF2-NRST: R65.1, S1.2, U$2.3 (PF2-NRST)
PF4-BOOT0: JP3.2, U$2.20 (PF4-BOOT0)
ROW_DATA_IN: U$2.13 (PA11); also elsewhere on the board
ROW_RCLK_IN: U$2.11 (PA9-OSC32OUT); also elsewhere on the board
ROW_SCLK_IN: U$2.12 (PA10-OSC32IN); also elsewhere on the board
USB_N: J14.D-, U$1.P$2 (UD-)
USB_P: J14.D+, U$1.P$1 (UD+)
VBUS: C10.1, IC2.1 (VIN), J14.VBUS

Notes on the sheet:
https://www.segger.com/products/debug-probes/j-link/accessories/adapters/9-pin-cortex-m-adapter/

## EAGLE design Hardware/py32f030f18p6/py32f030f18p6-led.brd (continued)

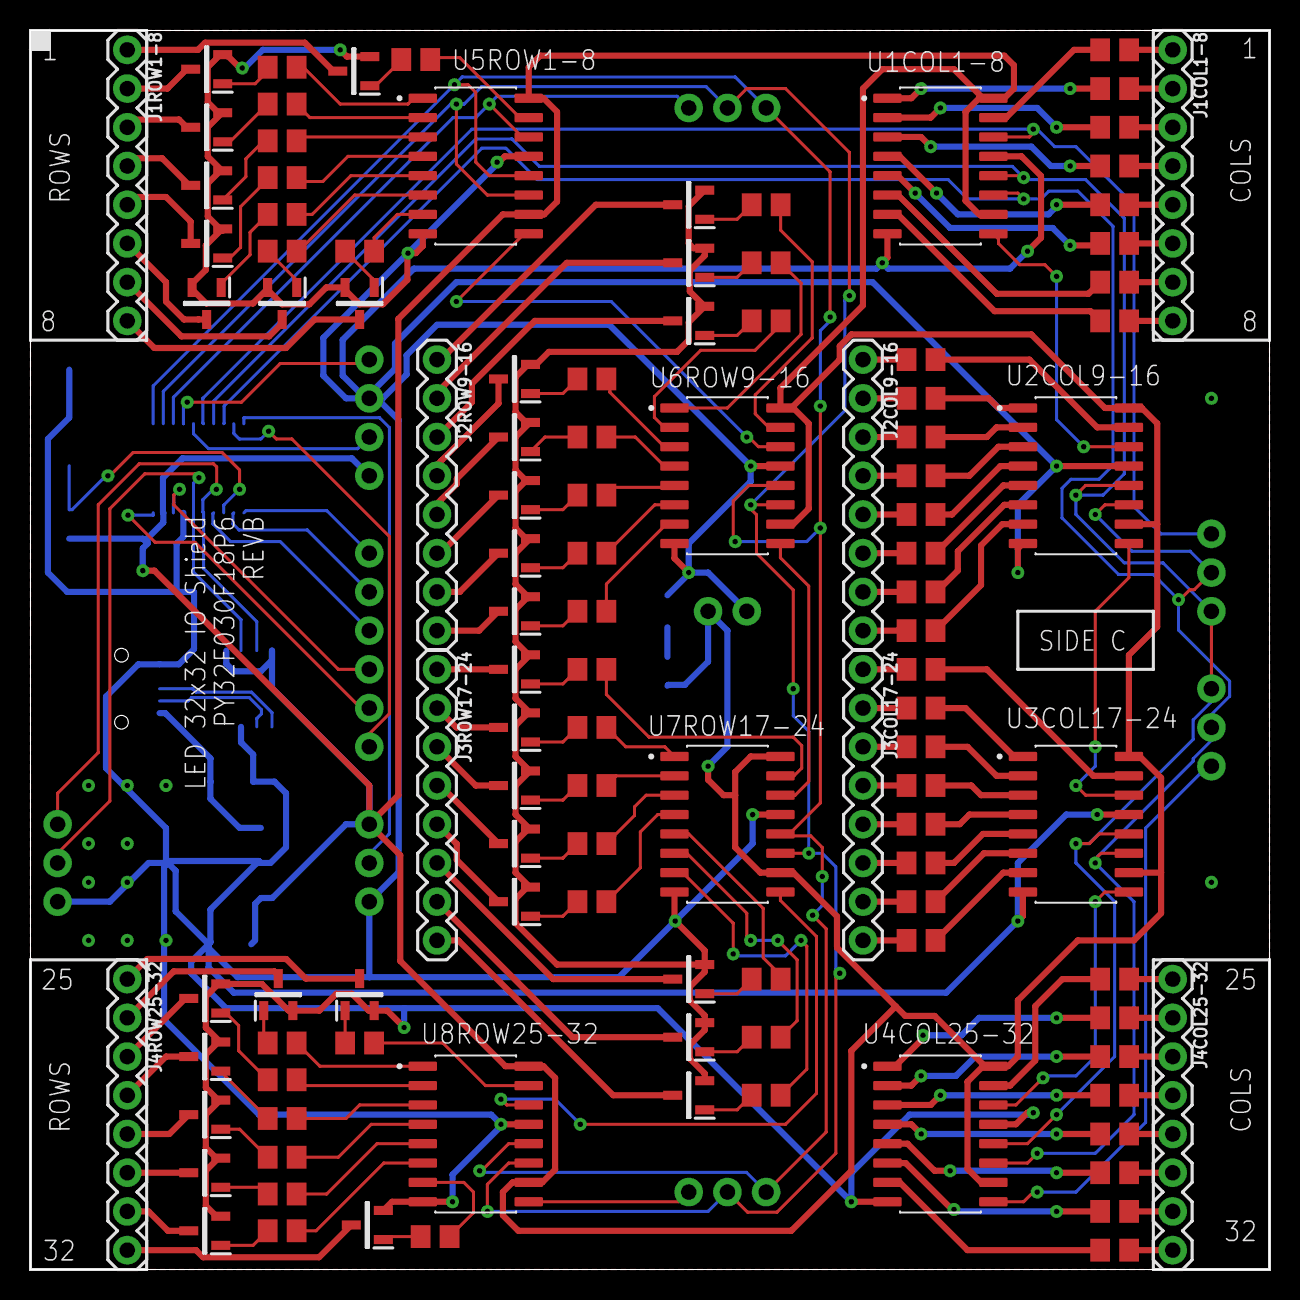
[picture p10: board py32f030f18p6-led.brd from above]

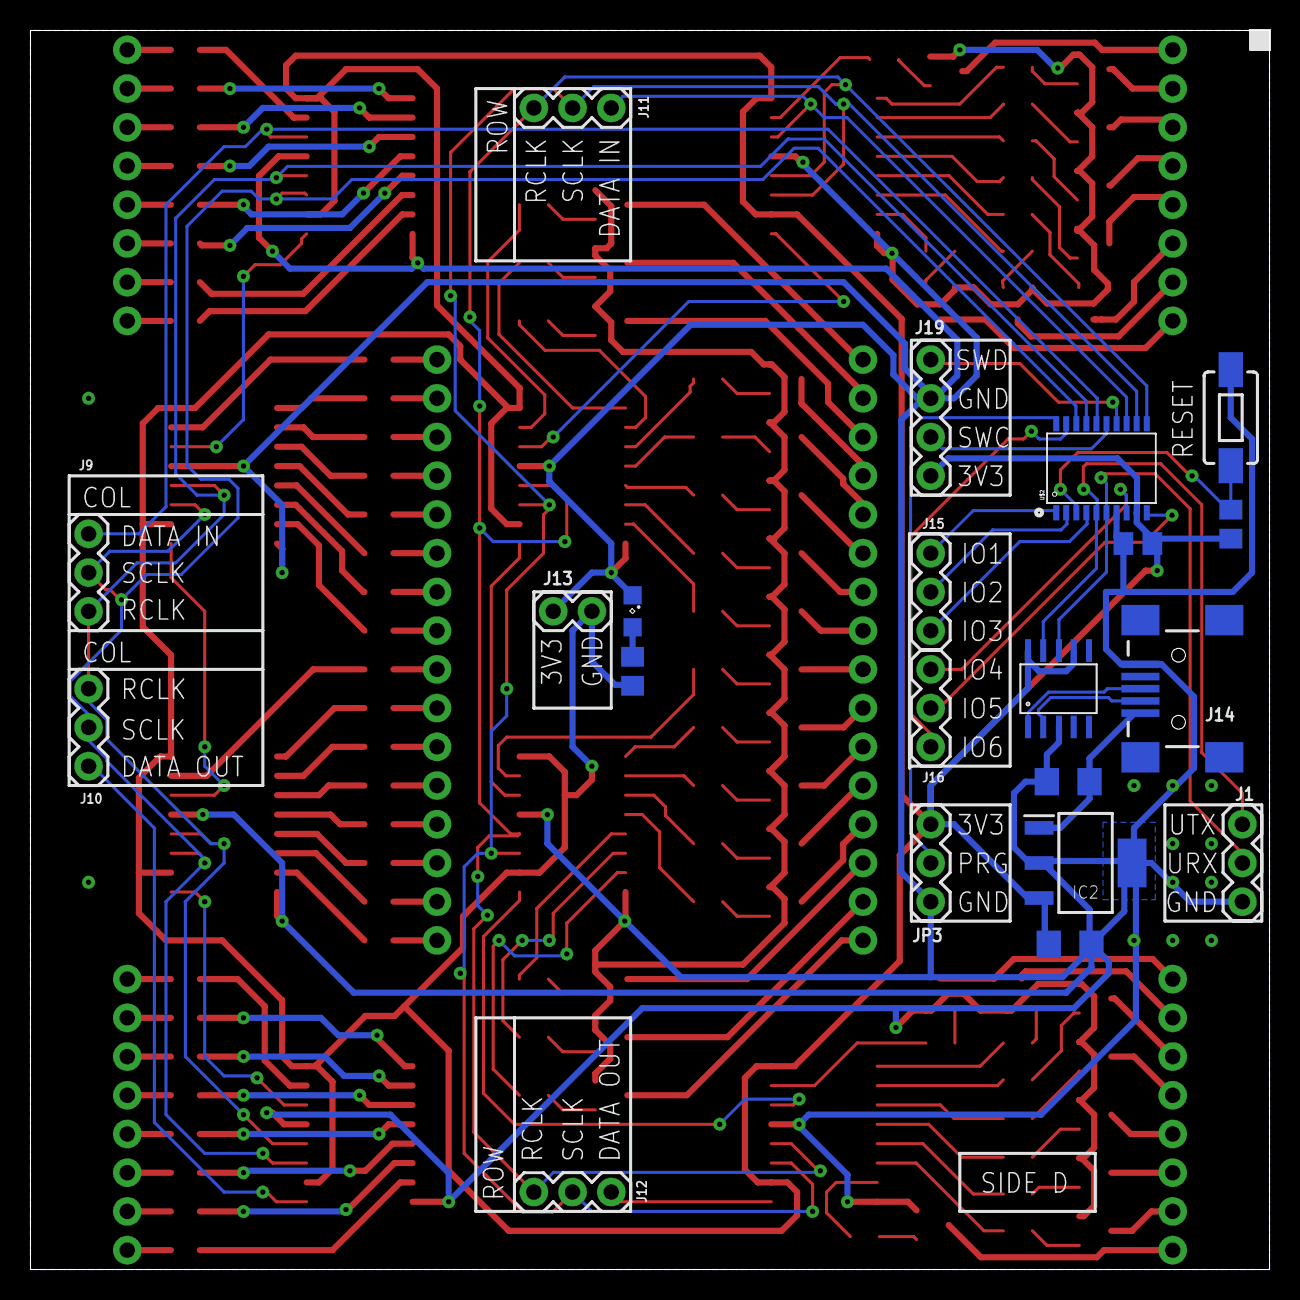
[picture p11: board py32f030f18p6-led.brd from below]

Board: 2 copper layers, 81.3 x 81.3 mm, 133 parts (21 on the bottom side), 192 nets.

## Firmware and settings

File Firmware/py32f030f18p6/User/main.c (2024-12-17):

/**
  ******************************************************************************
  * @file    main.c
  * @author  MCU Application Team
  * @brief   Main program body
  ******************************************************************************
  * @attention
  *
  * <h2><center>&copy; Copyright (c) Puya Semiconductor Co.
  * All rights reserved.</center></h2>
  *
  * <h2><center>&copy; Copyright (c) 2016 STMicroelectronics.
  * All rights reserved.</center></h2>
  *
  * This software component is licensed by ST under BSD 3-Clause license,
  * the "License"; You may not use this file except in compliance with the
  * License. You may obtain a copy of the License at:
  *                        opensource.org/licenses/BSD-3-Clause
  *
  ******************************************************************************
  */

#include "main.h"

static void APP_SystemClockConfig(void);
static void APP_GPIOConfig(void);

#define NELEMS(x)  (sizeof(x) / sizeof((x)[0]))

struct task_s { 

	uint32_t lastTick;
	uint32_t periodTick;
	void (*func)(void);
};


/*

		SR1

		PA11 - ROW_DATA_IN  Data    14
		PA10 - ROW_SCLK_IN  Clock   11
		PA9  - ROW_RCLK_IN  Latch   12

		SR2

		PB4  - COL_DATA_IN	Data
		PB6  - COL_SCLK_IN	Clock
		PB5  - COL_RCLK_IN	Latch

*/

#define ID_ROW 1
#define ID_COL 2

#define MAX_ROW   32
#define MAX_COL   32
#define MAX_DEPTH 4

static uint8_t screen[MAX_DEPTH][MAX_ROW][MAX_COL/8]; 
    
static void outputBitmapX(uint8_t *ptr) {

	LL_GPIO_TogglePin(GPIOA, LL_GPIO_PIN_8);					// GPIO5

	for (int row=0; row<MAX_ROW; row++) {
		
		LL_GPIO_ResetOutputPin(GPIOA, LL_GPIO_PIN_9); 					// ROW LATCH

		if (row == 0) {
			LL_GPIO_SetOutputPin(GPIOA, LL_GPIO_PIN_11);					// ROW DATA
    } else {
			LL_GPIO_ResetOutputPin(GPIOA, LL_GPIO_PIN_11);				// ROW DATA
    }

		LL_GPIO_SetOutputPin(GPIOA, LL_GPIO_PIN_10);						// ROW CLOCK
		LL_GPIO_ResetOutputPin(GPIOA, LL_GPIO_PIN_10);					// ROW CLOCK
				
		LL_GPIO_ResetOutputPin(GPIOB, LL_GPIO_PIN_5);						// COL LATCH


		ptr += (MAX_COL/8)-1;
				
		for (int k=0; k<(MAX_COL/8); k++) {

			uint8_t value = *ptr--;
	
			for(int i=0; i<8; i++) {
				
					if (value & 0x1) {
							LL_GPIO_SetOutputPin(GPIOB, LL_GPIO_PIN_4);		// COL DATA
					} else {
							LL_GPIO_ResetOutputPin(GPIOB, LL_GPIO_PIN_4);	// COL DATA
					}

					LL_GPIO_SetOutputPin(GPIOB, LL_GPIO_PIN_6);				// COL CLOCK																					
					LL_GPIO_ResetOutputPin(GPIOB, LL_GPIO_PIN_6);			// COL CLOCK

					value = value >> 1;
			}
		}
				
		ptr++;		
		ptr += (MAX_COL/8);
				
		LL_GPIO_SetOutputPin(GPIOB, LL_GPIO_PIN_5);							// COL LATCHs
				
		LL_GPIO_SetOutputPin(GPIOA, LL_GPIO_PIN_9);							// ROW LATCH
	}
	
	LL_GPIO_ResetOutputPin(GPIOA, LL_GPIO_PIN_9);							// ROW LATCH
	LL_GPIO_ResetOutputPin(GPIOA, LL_GPIO_PIN_11);						// ROW DATA

	LL_GPIO_SetOutputPin(GPIOA, LL_GPIO_PIN_10);							// ROW CLOCK
	LL_GPIO_ResetOutputPin(GPIOA, LL_GPIO_PIN_10);						// ROW CLOCK


	LL_GPIO_ResetOutputPin(GPIOB, LL_GPIO_PIN_5);							// COL LATCH

	for (int k=0; k<4; k++) {

		uint8_t value = 0;

		for(int i=0; i<8; i++) {
			
				if (value & 0x1) {
						LL_GPIO_SetOutputPin(GPIOB, LL_GPIO_PIN_4);			// COL DATA
				} else {
						LL_GPIO_ResetOutputPin(GPIOB, LL_GPIO_PIN_4);		// COL DATA
				}

				LL_GPIO_SetOutputPin(GPIOB, LL_GPIO_PIN_6);					// COL CLOCK																																
				LL_GPIO_ResetOutputPin(GPIOB, LL_GPIO_PIN_6);				// COL CLOCK

				value = value >> 1;
		}
	}
		
	LL_GPIO_SetOutputPin(GPIOB, LL_GPIO_PIN_5);								// COL LATCH

	LL_GPIO_SetOutputPin(GPIOA, LL_GPIO_PIN_9);								// ROW LATCH
}




static void outputBitmap(void) {

	static int i = 0;

	outputBitmapX((uint8_t *)&screen[i]);
	
	i++;
	if (i == MAX_DEPTH) {
		i = 0;
	}
}




static void updateBitmap(void) {

    static int col = 0;
    static int row = 0;
    static int lcol = 0;
    static int lrow = 0;
		static int xxx = 3;
		static int lxxx = 3;

    screen[0][lrow][lxxx] &= ~(1 << lcol);    
    screen[0][row][xxx] |= 1 << col;

    lcol = col;
    lrow = row;
		lxxx = xxx;
    
    
    col++;
    if (col >= 8) {
				xxx--;			
        col = 0;
				if (xxx < 0) {
					xxx = 3;
					row++;
					if (row >= 8) {
							row = 0;            
					}
				}
    }    
}


volatile static uint32_t systickCnt;

void SysTick_Handler(void) {
  systickCnt++;
}

const uint8_t nfont[128][8] = {
	
	{ 0x00, 0x00, 0x00, 0x00, 0x00, 0x00, 0x00, 0x00 }, // 0
	{ 0x00, 0x00, 0x00, 0x00, 0x00, 0x00, 0x00, 0x00 },
	{ 0x00, 0x00, 0x00, 0x00, 0x00, 0x00, 0x00, 0x00 },
	{ 0x00, 0x00, 0x00, 0x00, 0x00, 0x00, 0x00, 0x00 },
	{ 0x00, 0x00, 0x00, 0x00, 0x00, 0x00, 0x00, 0x00 },
	{ 0x00, 0x00, 0x00, 0x00, 0x00, 0x00, 0x00, 0x00 },
	{ 0x00, 0x00, 0x00, 0x00, 0x00, 0x00, 0x00, 0x00 },
	{ 0x00, 0x00, 0x00, 0x00, 0x00, 0x00, 0x00, 0x00 },
	{ 0x00, 0x00, 0x00, 0x00, 0x00, 0x00, 0x00, 0x00 },
	{ 0x00, 0x00, 0x00, 0x00, 0x00, 0x00, 0x00, 0x00 },
	
	{ 0x00, 0x00, 0x00, 0x00, 0x00, 0x00, 0x00, 0x00 }, // 10
	{ 0x00, 0x00, 0x00, 0x00, 0x00, 0x00, 0x00, 0x00 },
	{ 0x00, 0x00, 0x00, 0x00, 0x00, 0x00, 0x00, 0x00 },
	{ 0x00, 0x00, 0x00, 0x00, 0x00, 0x00, 0x00, 0x00 },
	{ 0x00, 0x00, 0x00, 0x00, 0x00, 0x00, 0x00, 0x00 },
	{ 0x00, 0x00, 0x00, 0x00, 0x00, 0x00, 0x00, 0x00 },
	{ 0x00, 0x00, 0x00, 0x00, 0x00, 0x00, 0x00, 0x00 },
	{ 0x00, 0x00, 0x00, 0x00, 0x00, 0x00, 0x00, 0x00 },
	{ 0x00, 0x00, 0x00, 0x00, 0x00, 0x00, 0x00, 0x00 },
	{ 0x00, 0x00, 0x00, 0x00, 0x00, 0x00, 0x00, 0x00 },
	
	{ 0x00, 0x00, 0x00, 0x00, 0x00, 0x00, 0x00, 0x00 }, // 20
	{ 0x00, 0x00, 0x00, 0x00, 0x00, 0x00, 0x00, 0x00 },
	{ 0x00, 0x00, 0x00, 0x00, 0x00, 0x00, 0x00, 0x00 },
	{ 0x00, 0x00, 0x00, 0x00, 0x00, 0x00, 0x00, 0x00 },
	{ 0x00, 0x00, 0x00, 0x00, 0x00, 0x00, 0x00, 0x00 },
	{ 0x00, 0x00, 0x00, 0x00, 0x00, 0x00, 0x00, 0x00 },
	{ 0x00, 0x00, 0x00, 0x00, 0x00, 0x00, 0x00, 0x00 },
	{ 0x00, 0x00, 0x00, 0x00, 0x00, 0x00, 0x00, 0x00 },
	{ 0x00, 0x00, 0x00, 0x00, 0x00, 0x00, 0x00, 0x00 },
	{ 0x00, 0x00, 0x00, 0x00, 0x00, 0x00, 0x00, 0x00 },
		
	{ 0x00, 0x00, 0x00, 0x00, 0x00, 0x00, 0x00, 0x00 }, // 30
	{ 0x00, 0x00, 0x00, 0x00, 0x00, 0x00, 0x00, 0x00 },
	{ 0x00, 0x00, 0x00, 0x00, 0x00, 0x00, 0x00, 0x00 },
	{ 0x00, 0x00, 0x00, 0x00, 0x00, 0x00, 0x00, 0x00 },
	{ 0x00, 0x00, 0x00, 0x00, 0x00, 0x00, 0x00, 0x00 },
	{ 0x00, 0x00, 0x00, 0x00, 0x00, 0x00, 0x00, 0x00 },
	{ 0x00, 0x00, 0x00, 0x00, 0x00, 0x00, 0x00, 0x00 },
	{ 0x00, 0x00, 0x00, 0x00, 0x00, 0x00, 0x00, 0x00 },
	{ 0x00, 0x00, 0x00, 0x00, 0x00, 0x00, 0x00, 0x00 },
	{ 0x00, 0x00, 0x00, 0x00, 0x00, 0x00, 0x00, 0x00 },

	{ 0x00, 0x00, 0x00, 0x00, 0x00, 0x00, 0x00, 0x00 }, // 40
	{ 0x00, 0x00, 0x00, 0x00, 0x00, 0x00, 0x00, 0x00 },
	{ 0x00, 0x00, 0x00, 0x00, 0x00, 0x00, 0x00, 0x00 },
	{ 0x00, 0x00, 0x00, 0x00, 0x00, 0x00, 0x00, 0x00 },
	{ 0x00, 0x00, 0x00, 0x00, 0x00, 0x00, 0x00, 0x00 },
	{ 0x00, 0x00, 0x00, 0x00, 0x00, 0x00, 0x00, 0x00 },
	{ 0x00, 0x00, 0x00, 0x00, 0x00, 0x00, 0x00, 0x00 },
	{ 0x00, 0x00, 0x00, 0x00, 0x00, 0x00, 0x00, 0x00 },
	{ 0x70, 0x88, 0x98, 0xA8, 0xC8, 0x88, 0x70, 0x00 }, // 48 - '0'
	{ 0x20, 0x60, 0x20, 0x20, 0x20, 0x20, 0x70, 0x00 },

	{ 0x70, 0x88, 0x08, 0x10, 0x20, 0x40, 0xF8, 0x00 }, // 50
	{ 0xF0, 0x08, 0x08, 0x70, 0x08, 0x08, 0xF0, 0x00 },
	{ 0x88, 0x88, 0x88, 0xF8, 0x08, 0x08, 0x08, 0x00 },
	{ 0xF8, 0x80, 0x80, 0xF0, 0x08, 0x08, 0xF0, 0x00 },
	{ 0x70, 0x80, 0x80, 0xF0, 0x88, 0x88, 0x70, 0x00 },
	{ 0xF8, 0x08, 0x08, 0x10, 0x20, 0x20, 0x20, 0x00 },
	{ 0x70, 0x88, 0x88, 0x70, 0x88, 0x88, 0x70, 0x00 }, 
	{ 0x70, 0x88, 0x88, 0x78, 0x08, 0x88, 0x70, 0x00 }, // 57 - '9'
	{ 0x00, 0x00, 0x00, 0x00, 0x00, 0x00, 0x00, 0x00 },
	{ 0x00, 0x00, 0x00, 0x00, 0x00, 0x00, 0x00, 0x00 },
	
	{ 0x70, 0x88, 0x08, 0x10, 0x20, 0x40, 0xF8, 0x00 }, // 60
	{ 0xF0, 0x08, 0x08, 0x70, 0x08, 0x08, 0xF0, 0x00 },
	{ 0x88, 0x88, 0x88, 0xF8, 0x08, 0x08, 0x08, 0x00 },
	{ 0xF8, 0x80, 0x80, 0xF0, 0x08, 0x08, 0xF0, 0x00 },
	{ 0x70, 0x80, 0x80, 0xF0, 0x88, 0x88, 0x70, 0x00 },
	{ 0x70, 0x88, 0x88, 0xF8, 0x88, 0x88, 0x88, 0x00 }, // 65 - 'A'
	{ 0xF0, 0x88, 0x88, 0xF0, 0x88, 0x88, 0xF0, 0x00 },
	{ 0x70, 0x88, 0x80, 0x80, 0x80, 0x88, 0x70, 0x00 },
	{ 0xF0, 0x88, 0x88, 0x88, 0x88, 0x88, 0xF0, 0x00 },
	{ 0xF8, 0x80, 0x80, 0xF0, 0x80, 0x80, 0xF8, 0x00 },
	
	{ 0xF8, 0x80, 0x80, 0xF0, 0x80, 0x80, 0x80, 0x00 }, // 70
	{ 0x70, 0x88, 0x80, 0x98, 0x88, 0x88, 0x70, 0x00 },
	{ 0x88, 0x88, 0x88, 0xF8, 0x88, 0x88, 0x88, 0x00 },
	{ 0xF8, 0x20, 0x20, 0x20, 0x20, 0x20, 0xF8, 0x00 },
	{ 0xF8, 0x10, 0x10, 0x10, 0x90, 0x90, 0x60, 0x00 },
	{ 0x88, 0x90, 0xA0, 0xC0, 0xA0, 0x90, 0x88, 0x00 },
	{ 0x80, 0x80, 0x80, 0x80, 0x80, 0x80, 0xF8, 0x00 },
	{ 0xD8, 0xA8, 0xA8, 0x88, 0x88, 0x88, 0x88, 0x00 },
	{ 0x88, 0xC8, 0xA8, 0xA8, 0xA8, 0x98, 0x88, 0x00 },
	{ 0x70, 0x88, 0x88, 0x88, 0x88, 0x88, 0x70, 0x00 },

	{ 0xF0, 0x88, 0x88, 0xF0, 0x80, 0x80, 0x80, 0x00 }, // 80
	{ 0x70, 0x88, 0x88, 0x88, 0xA8, 0x98, 0x78, 0x00 },
	{ 0xF0, 0x88, 0x88, 0xF0, 0xA0, 0x90, 0x88, 0x00 },
	{ 0x70, 0x88, 0x80, 0x70, 0x08, 0x88, 0x70, 0x00 },
	{ 0xF8, 0x20, 0x20, 0x20, 0x20, 0x20, 0x20, 0x00 },
	{ 0x88, 0x88, 0x88, 0x88, 0x88, 0x88, 0x70, 0x00 },
	{ 0x88, 0x88, 0x88, 0x50, 0x50, 0x20, 0x20, 0x00 },
	{ 0x88, 0x88, 0x88, 0xA8, 0xA8, 0x50, 0x50, 0x00 },
	{ 0x88, 0x50, 0x50, 0x20, 0x50, 0x50, 0x88, 0x00 },
	{ 0x88, 0x88, 0x50, 0x20, 0x20, 0x20, 0x20, 0x00 },

	{ 0xF8, 0x08, 0x10, 0x20, 0x40, 0x80, 0xF8, 0x00 }, // 90 - 'Z'
	{ 0x00, 0x00, 0x00, 0x00, 0x00, 0x00, 0x00, 0x00 },
	{ 0x00, 0x00, 0x00, 0x00, 0x00, 0x00, 0x00, 0x00 },
	{ 0x00, 0x00, 0x00, 0x00, 0x00, 0x00, 0x00, 0x00 },
	{ 0x00, 0x00, 0x00, 0x00, 0x00, 0x00, 0x00, 0x00 },
	{ 0x00, 0x00, 0x00, 0x00, 0x00, 0x00, 0x00, 0x00 },
	{ 0x00, 0x00, 0x00, 0x00, 0x00, 0x00, 0x00, 0x00 },
	{ 0x00, 0x00, 0x00, 0x78, 0x88, 0x88, 0x78, 0x00 }, // 97 - 'a'
	{ 0x80, 0x80, 0x80, 0xF0, 0x88, 0x88, 0xF0, 0x00 },
	{ 0x00, 0x00, 0x70, 0x88, 0x80, 0x88, 0x70, 0x00 },
	
	{ 0x08, 0x08, 0x08, 0x78, 0x88, 0x88, 0x78, 0x00 }, // 100
	{ 0x00, 0x00, 0x70, 0x88, 0xF8, 0x80, 0x70, 0x00 },
	{ 0x30, 0x48, 0x40, 0xE0, 0x40, 0x40, 0x40, 0x00 },
	{ 0x70, 0x88, 0x88, 0x78, 0x08, 0x88, 0x70, 0x00 },
	{ 0x80, 0x80, 0x80, 0xF0, 0x88, 0x88, 0x88, 0x00 },
	{ 0x00, 0x80, 0x00, 0x80, 0x80, 0x80, 0x80, 0x00 },
	{ 0x10, 0x00, 0x10, 0x10, 0x10, 0x90, 0x60, 0x00 },
	{ 0x80, 0x80, 0x88, 0x90, 0xA0, 0xD0, 0x88, 0x00 },
	{ 0x80, 0x80, 0x80, 0x80, 0x80, 0x80, 0x40, 0x00 },
	{ 0x00, 0x00, 0x00, 0xD0, 0xA8, 0xA8, 0xA8, 0x00 },
	
	{ 0x00, 0x00, 0x00, 0xF0, 0x88, 0x88, 0x88, 0x00 }, // 110
	{ 0x00, 0x00, 0x00, 0x70, 0x88, 0x88, 0x70, 0x00 },
	{ 0x00, 0x70, 0x88, 0x88, 0xF0, 0x80, 0x80, 0x00 },
	{ 0x70, 0x90, 0x90, 0x70, 0x10, 0x18, 0x10, 0x00 },
	{ 0x00, 0x00, 0x00, 0xB8, 0xC0, 0x80, 0x80, 0x00 },
	{ 0x00, 0x00, 0x78, 0x80, 0x70, 0x08, 0xF0, 0x00 },
	{ 0x00, 0x00, 0x20, 0x70, 0x20, 0x20, 0x20, 0x00 },
	{ 0x00, 0x00, 0x00, 0x88, 0x88, 0x88, 0x78, 0x00 },
	{ 0x00, 0x00, 0x00, 0x88, 0x50, 0x50, 0x20, 0x00 },
	{ 0x00, 0x00, 0x00, 0x88, 0xA8, 0xA8, 0x50, 0x00 },

	{ 0x00, 0x00, 0x88, 0x50, 0x20, 0x50, 0x88, 0x00 }, // 120
	{ 0x00, 0x00, 0x88, 0x88, 0x78, 0x08, 0xF0, 0x00 },
	{ 0x00, 0x00, 0xF8, 0x10, 0x20, 0x40, 0xF8, 0x00 }, // 122 - 'z'
	{ 0x00, 0x00, 0x00, 0x00, 0x00, 0x00, 0x00, 0x00 },
	{ 0x00, 0x00, 0x00, 0x00, 0x00, 0x00, 0x00, 0x00 },
	{ 0x00, 0x00, 0x00, 0x00, 0x00, 0x00, 0x00, 0x00 },
	{ 0x00, 0x00, 0x00, 0x00, 0x00, 0x00, 0x00, 0x00 },
	{ 0x00, 0x00, 0x00, 0x00, 0x00, 0x00, 0x00, 0x00 },	
	
};


static void drawBlankCharX(int row, int col, uint8_t *ptr) {

	int coff = col % 8;
	ptr += (row * MAX_COL/8) + (col/8);
	
	for (int i=0; i<8; i++) {
		
		*ptr &= ~(252 >> coff);		
		if (coff) {
			*(ptr+1) &= ~(252 << (8-coff));		
		}
		
		ptr += MAX_COL/8;
	}
}

static void drawBlankChar(int row, int col, int depth) {
	
	drawBlankCharX(row, col, (uint8_t *)&screen[depth]);
}




static void drawCharX(int row, int col, uint8_t *ptr, int c) {
	
	if (col < 0) {
		
		if (col >= -5) {
			
			int coff = col * -1;
			ptr += (row * MAX_COL/8);

			for (int i=0; i<8; i++) {
			
				*ptr &= ~(252 << coff);
				*ptr |= nfont[c][i] << coff;
				ptr += MAX_COL/8;
			}			
		}
		
		// TODO - testme
		
	} else if ((col >= MAX_COL-5) && ( col < MAX_COL)) {

		int coff = col % 8;
		ptr += (row * MAX_COL/8) + (col/8);
			
		for (int i=0; i<8; i++) {
			
			*ptr &= ~(252 >> coff);		
			*ptr |= nfont[c][i] >> coff;
			
			ptr += MAX_COL/8;
		}
		
		// TODO - testme
		
	} else if ( col < MAX_COL) {

		int coff = col % 8;
		ptr += (row * MAX_COL/8) + (col/8);
			
		for (int i=0; i<8; i++) {
			
			*ptr &= ~(252 >> coff);		
			*ptr |= nfont[c][i] >> coff;
			if (coff) {
				*(ptr+1) &= ~(252 << (8-coff));		
				*(ptr+1) |= nfont[c][i] << (8-coff);
			}
			
			ptr += MAX_COL/8;
		}
	}
}

static void drawCharY(int row, int col, int depth, int c) {

	drawCharX(row, col, (uint8_t *)&screen[depth], c);
}

static void drawChar(int row, int col, int intensity, int c) {

	if (intensity > MAX_DEPTH-1) {
		intensity = MAX_DEPTH-1;
	}		
	
	for (int i=0; i<=intensity; i++) {
		drawCharY(row, col, i, c);
	}
}

static void drawString(int row, int col, int intensity, char *ptr) {
	
		while (*ptr) {			
			drawChar(row, col, intensity, *ptr);
			col += 6;
			ptr++;
		}	
}



static void updateBitmap2(void) {

	static int i = 0;

	drawChar(0, 0, 0, '0'+i);
	
	i++;
	if (i > 9) {
		i = 0;
	}
}


int random(unsigned long count);

//1+MWC%10; would provide the proverbial "take a number from 1 to 10", (but with not quite, but virtually, equal probabilities)


static void setPixelY(int row, int col, int depth) {
	
	uint8_t *ptr = (uint8_t *)&screen[depth];

	int coff = col % 8;
	ptr += (row * MAX_COL/8) + (col/8);

	*ptr &= ~(0x80 >> coff) ;
	*ptr |= (0x80 >> coff);
}


static void setPixel(int row, int col, int intensity) {

	for (int i=0; i<=intensity; i++) {
		setPixelY(row, col, i);
	}
}


static void resetPixel(int row, int col) {
	
	for (int i=0; i<MAX_DEPTH; i++) {
		
		uint8_t *ptr = (uint8_t *)&screen[i];

		int coff = col % 8;
		ptr += (row * MAX_COL/8) + (col/8);
	
		*ptr &= ~(0x80 >> coff) ;		
	}
}


static void updateBitmap3(void) {

		for (int i=0; i<10; i++) {

				int row = random(10);
				int col = random(32);
		
				resetPixel(row, col);						
		}


		for (int i=0; i<10; i++) {

				int row = random(11);
				int col = random(32);
		
				resetPixel(21+row, col);						
		}

}

static void updateBitmap4(void) {

		for (int i=0; i<10; i++) {

				int row = random(10);
				int col = random(32);
				int intensity = random(4);
		
				setPixel(row, col, intensity);						
		}


		for (int i=0; i<10; i++) {

				int row = random(11);
				int col = random(32);
				int intensity = random(4);
		
				setPixel(21+row, col, intensity);						
		}
}



static void updateBitmap5(void) {

	static int i = MAX_COL;
	
	                    //012345678901234567890
	drawString(12, i, 3, "MERRY CHRISTMAS");
	i--;
	if (i < (-15*6)) {
		i = MAX_COL;
	}
}





int main(void)
{
    struct task_s tasks[] = {

		{ 0, 0,  outputBitmap },  /* update a different row every 10ms */
//		{ 0, 50, updateBitmap2 },  /* 1S animations written to bitmap */
		{ 0, 1000, updateBitmap3 },  /* 1S animations written to bitmap */
		{ 0, 1000, updateBitmap4 },  /* 1S animations written to bitmap */
		{ 0, 50, updateBitmap5 },  /* 0.5S animations written to bitmap */
//		{ 0, 10,  updateBitmap },  /* 50ms animations written to bitmap */
	};
	
	
	
  APP_SystemClockConfig();
  APP_GPIOConfig();

	LL_SYSTICK_EnableIT();

  while (1)
  {
#if 0		
    LL_GPIO_TogglePin(GPIOB, LL_GPIO_PIN_5);
    LL_mDelay(1000);
#else		
		struct task_s *task = tasks;
	
		for (unsigned int i=0; i<NELEMS(tasks); i++) {
		 		 
			if ((task->periodTick == 0) ||
				  ((uint32_t)(systickCnt - task->lastTick) >= task->periodTick)) {
                
				(*task->func)();
				task->lastTick = systickCnt;
			}
			
			task++;
		}
#endif		
  }
}

//#define OLDCODE

#ifndef OLDCODE
static void APP_SystemClockConfig(void)
{
  LL_UTILS_ClkInitTypeDef ClkInit = { LL_RCC_SYSCLK_DIV_1, LL_RCC_APB1_DIV_1 };

  LL_RCC_HSI_Enable();
  LL_RCC_HSI_SetCalibFreq(LL_RCC_HSICALIBRATION_24MHz);
  while (LL_RCC_HSI_IsReady() != 1);
  LL_PLL_ConfigSystemClock_HSI(&ClkInit);
  SysTick_Config(48000);
  NVIC_SetPriority(SysTick_IRQn, 0);
}
#else
static void APP_SystemClockConfig(void)
{
  LL_UTILS_ClkInitTypeDef UTILS_ClkInitStruct;
  //Enable internal high speed
  LL_RCC_HSI_Enable();
  //Set to 24MHz, the frequency can be fine-tuned here, and the higher the value, the faster the frequency
  LL_RCC_HSI_SetCalibFreq(LL_RCC_HSICALIBRATION_24MHz);
  //Wait for stabilization
  while (LL_RCC_HSI_IsReady() != 1);
  //AHB does not divide the frequency
  UTILS_ClkInitStruct.AHBCLKDivider = LL_RCC_SYSCLK_DIV_1;
  //APB is not crossover
  UTILS_ClkInitStruct.APB1CLKDivider = LL_RCC_APB1_DIV_1;
  //Set the system clock source to PLL+HSI, note the method name 
  LL_PLL_ConfigSystemClock_HSI(&UTILS_ClkInitStruct);
  //Update the settings for SysTick
  LL_InitTick(48000000U, 1000U);
}
#endif

static void APP_GPIOConfig(void)
{
  LL_IOP_GRP1_EnableClock(LL_IOP_GRP1_PERIPH_GPIOA);
  LL_GPIO_SetPinMode(GPIOA, LL_GPIO_PIN_9, LL_GPIO_MODE_OUTPUT);
  LL_GPIO_SetPinMode(GPIOA, LL_GPIO_PIN_10, LL_GPIO_MODE_OUTPUT);
  LL_GPIO_SetPinMode(GPIOA, LL_GPIO_PIN_11, LL_GPIO_MODE_OUTPUT);


  LL_GPIO_SetPinMode(GPIOA, LL_GPIO_PIN_8, LL_GPIO_MODE_OUTPUT);	// GPIO5


	
  LL_IOP_GRP1_EnableClock(LL_IOP_GRP1_PERIPH_GPIOB);
  LL_GPIO_SetPinMode(GPIOB, LL_GPIO_PIN_4, LL_GPIO_MODE_OUTPUT);
  LL_GPIO_SetPinMode(GPIOB, LL_GPIO_PIN_5, LL_GPIO_MODE_OUTPUT);
  LL_GPIO_SetPinMode(GPIOB, LL_GPIO_PIN_6, LL_GPIO_MODE_OUTPUT);	
}

void APP_ErrorHandler(void)
{
  while (1);
}

#ifdef  USE_FULL_ASSERT
void assert_failed(uint8_t *file, uint32_t line)
{
  while (1);
}
#endif /* USE_FULL_ASSERT */

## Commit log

2024-10-24 Adding hardware and firmware
    firmware is just a skeleton for now
    [common.brd, common.sch, font.xlsx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]
2024-11-07 Got row/col reversed
    [common.brd, common.sch, py32f030f18p6-led.brd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]
2024-11-10 Added rx/tx breakout
    [py32f030f18p6-led.brd, py32f030f18p6-led.sch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]
2024-11-11 Final checks ( removed dimensions ) regenerate gerbers to submit to jlpcb
    [common.brd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]
2024-11-28 MCU running at 48Mhz ( 24Mhz Internal * 2 PLL )
    Display appears flicker free and leds same brightness, simple test running displaying dots. Need to investigate divider on one of the busses, I think I need a few cycles delay between toggling the sh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
2024-12-09 Refresh 32x32 at 1ms, 4 planes at 4ms, so 250Hz refresh.
    Refresh 32x32 at 1ms, 4 planes at 4ms, so 250Hz refresh. Planes represent brightness, same bit across 4 planes will light LED brightest, single bit on 1 plane will light LED dimmest. Using nordic pow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

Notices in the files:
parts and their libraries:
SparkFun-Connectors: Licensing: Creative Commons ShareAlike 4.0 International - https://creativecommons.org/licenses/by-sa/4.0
